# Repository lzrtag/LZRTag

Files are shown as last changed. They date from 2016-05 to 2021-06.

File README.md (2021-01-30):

# LZRTag
### ESP32-Based Lasertag

Ever wanted to set up your own system of Lasertag?
Interested in having an easily modifiable system to create your own gamemodes and styles with?
Or just looking for a cool project to try out?
Well, why not take a spin at this!

*Note:* This project is not in serious development. I (Xasin) take no responsibility for what is done with this code, and I can't guarantee it'll do exactly what I tell it to (even if I try to give it treats >:c)
However, it is a fully functional system, if you know how to use it, and it has proven itself
to be pretty reliable and useful!

## The components
In order to have a functional game, you will need at least the following:
- Two or more soldered Lasertag Sets
- A WiFi access point or a newtwork of points throughout the arena.
- A MQTT Server, preferrably in the local network, to reduce ping.
- And a system running Ruby 2.4 or better, to run the Lasertag Backend and your gamemodes

## The Electronics
*Attention:* The electronics aren't necessarily beginner-friendly. I've designed them with components no smaller than a TSOP package or a 0805 resistor, but the newer versions of the hardware do include two QFN Packages - one for a optional IMU, so it can be left out, and one for a standard I2S audio chip, for which you can use any breakout board that supports 44100Hz, 16 bit playback. If you have a hot air gun,
definitely make use of it!

The electronics are based around the ESP32, a fairly cheap, powerful, WiFi and Bluetooth capable chip. The PCB includes all necessary support structures, including a battery charge circuit and a USB to UART converter to reprogram and debug the ESP.
It comes with the following hardware:
- The ESP32 plus beefy voltage regulation, ESD protection, etc. It ain't gonna break!
- A MAX I2S decoder + amplifier, for on-board, high quality audio.
- A LSM6D IMU, to detect movement, collisions, gestures, etc.
- Peripherals to receive and send IR Signals (documented here: TODO)
- Feedback in the shape of WS2812 LEDs and a vibration motor
- Trigger, Gun Select and Reload buttons.

The vest connection is exposed with a D-SUB connector, and I2C lines are available to make
more complex add-ons easier to achieve. There's also a I2C breakout connection on the PCB itself!

The Vest itself can be as simple as a couple of Vishay 40kHz IR receivers and WS2812 LEDs, but
there is a connection for vest-specific haptic feedback, and via the I2C connection it's easy to add
more complex features.

To solder one, check out the Aisler project here: https://aisler.net/p/QLILZEMV
Or head to the "Electronics" folder and generate your own Gerber files!

## The Casing
The 3D printed casing I designed is totally optional - the electronics can be easily fitted into any other casing, provided it has space for a switch, a speaker and a couple of LEDs!
However, if you do want to print it out, there's the Fusion360 page here: https://a360.co/2Lbm2zJ

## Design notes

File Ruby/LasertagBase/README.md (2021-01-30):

# LZRTag base library gem

This is the full documentation of the LZRTag ruby gem library.
It includes examples for the different elements of this code, and even a basic
deathmatch game to show off the mechanics more interactively.

## Prerequisites
Let's first start off by installing and setting up everything that's needed
to run a LZRTag game. We'll assume you have at least one, preferrably as many as possible,
LZRTag hardware sets with the latest firmware - consult the [HackADay page](bit.ly/XASLZR) as well as the [GitHub Wiki page](https://github.com/XasWorks/LZRTag/wiki/Assembly) on soldering them up.  
We will also need a WiFi network and a MQTT Server, either local or hosted, like
Flespi.io, with the LZRTag hardware set up to connect to the server. Successful
connection is indicated by a smooth, very slow waver of the blue connection LED
on the sets. If you want to double-check connection you can subscribe to the
Lasertag/# topic on your MQTT server and check if the sets are pinging properly.

Once we are sure that the sets are connected properly run `gem install lzrtag-base`.
The latest ruby is recommended for performance reasons, however, this code should work
with anything above 2.3.

## Testing on IRB
As a first experience, I'd recommend playing with the interface class on the interactive
ruby console. It's a great way to see the immediate effects of various commands
on the set, and is kinda fun, too.

Let's first start up the console and require the library.

```IRB
irb(main):001:0> require 'lzrtag.rb'
=> true
irb(main):002:0>
```
This will load all necessary files, and will also provide a few helper functions
to access the correct classes etc.  
Next, let's establish an MQTT connection and start the handler.

```IRB
irb(main):002:0> mqtt = MQTT::SubHandler.new('localhost'); # Or your address
MQTT: localhost trying reconnect...
MQTT: localhost connected!
irb(main):003:0> handler = LZRTag.Handler.new(mqtt);
I LZR::Handler init finished
```

Awesome! The handler should now be connected to your server, and should have registered
new players. If you look at your MQTT Server, for example with MQTT-Spy, you
should see that any connected players will now have an ID.

Let's see what players the system has already registered:

```irb
irb(main):004:0> handler.each do |player| puts player; end;
#<Player:DEVICE_ID#OFFLINE, Team=0, Battery=4.19, Ping=218ms>
```

Players have a nice inspect function so they don't clutter the console too much when printed. Neat, huh?

Alright, we need to fetch one single player to play with. If you have a device ID
(their MAC, used on the MQTT network to identify them) you can use that, otherwise
use the ShotID (number, 0..255). Let's do  that now - and while we're at it,
let's identify the player:

```irb
irb(main):005:0> player = handler["BC.DD.C2.D0.63.F8"]
=> #<Player:#OFFLINE, Team=0, Battery=4.19, Heap=0, Ping=218ms>
irb(main):006:0> player.hit
```

You should have seen and heard one of the sets flashing up - that's the one we
just retrieved. We can also colour it green and make it a little brighter!

```irb
irb(main):007:0> player.team = 2
=> 2
irb(main):08:0> player.brightness = :active
=> :active
```

Alright, awesome - let's not go too deep into what you can do with the player.
That's what the Ruby documentation is for, after all.

## And now?
Well, more complex behaviours can be added with so-called hooks. These are extensions
that perform automated tasks based on different events in the game, and use the
internal "event system".  
There is a list of currently used events available, as well as documentation on
the hooks class. You can make your own, or use the standard hooks provided in this
library - it's up to you!

Since a game is way more than just behaviours though, there are also "Games".
Each game is a collection of hooks, which provide the behaviour of the game. However,
they also include a description of different phases - stuff like "initializing",
"playing", "selecting teams", etc.  
The application can seamlessly switch between phases of a game, with each phase
defining which hooks to enable or disable and what to do every game tick.

It's best to look right into the documentation on those classes, since demonstrating
them bit by bit isn't really possible.

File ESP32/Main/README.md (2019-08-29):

# The Lasertag ESP32 Core code

This code is what drives the newest version of the Lasertag.
Written in C++, this code here handles graphics, shot sounds, as well as communication with the Ruby-Side server code, via a MQTT Channel.

All hardware-related systems can be found under main/core/setup.cpp
Graphics are executed in main/fx/animatorThread.cpp, while gun profiles are found under main/weapons/

If you want to add your own weapon, animation feature, communication code or similar, it's best to open an issue and contact the team.
Documenting this work is a bit tough, but explaining specifics should be easy!

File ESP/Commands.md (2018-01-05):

### Immediate commands
Number | Short Desc. | Data
:--- | --- | ---
A000 | Shot cfg | 0 = Normal shot
E000 | Trigger status changed
E001 | Shot detected | Player, ShotID
A010 | Vibrate 	| Time (in MS, up to 2^16 ms)
A011 | Buzzer 	| Time (in ms), Start, End (in Hz)
A012 | Vest Blink Override | Level + time in segments

### Config commands
Number | Short Desc.
:--- | ---
A100 | Set Player ID
A101 | Set Player Team (0-7)
A110 | Set vibration pattern
A200 | Set vest visibility level

###### A200
Visibilitiy levels:
- 0 = Absolutely no lights whatsoever, dimmed nozzle flash.
- 1 = Occasional dimmed blink, dimmed nozzle flash.
- 2 = Occasional bright blink, full nozzle flash.
- 3 = Dimmed with occasional blink, full nozzle flash.
- 4 = Full light, full nozzle flash.
- 5 = Special Mode - Full with white flashes, full nozzle flash with dim background.
- 6 = Wave-Mode (in low brightness)
- 7 = Wave-Mode (in full brightness)

- 10 = Full brightness, constant white flashing. Used for hit and death animation

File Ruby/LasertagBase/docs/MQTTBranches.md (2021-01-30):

# MQTT Branch setup description

## Game Branches

- Lasertag/Game/Events/Hits
- Lasertag/Game/Controls/+
	- SetPhase
	- SetGame
- Lasertag/Game/Phase/Valid
- Lasertag/Game/ParticipatingPlayers
- Lasertag/Game/KnownGames
- Lasertag/Game/CurrentGame
- Lasertag/Game/Phase/Current

## Weapon Branches
The weapons are the main unit of the Lasertag system. As such, they use a specific
branch setup to minimize traffic to them, while making code maintaining easier.

The basic branch setup is:
> Lasertag/Players/**ID**/**Keys...**

- **ID** is the MAC of the Player, allowing unique identification of
	each set out of the box.
- **Key** is a one- or two-layer key of the attribute to change.
	Attributes are grouped, making it easier to subscribe to one group of attributes
	without having to worry about the others.

In the following, the different groups of keys will be outlined, followed by
a description of each attribute per group.

### Non-Grouped attributes

|Keys|Data|Descrition|Retained|
|--|--|--|--|
|Connection|String|LWT Topic of the sets. "OK" if connected.|Yes|

### Config attributes

Any attributes under this category can be found under "/CFG/**KEY**".
They are slow-changing configuration parameters for the weapons.

|Key|Data|Descrition|Retained|
|--|--|--|--|
|Team|STR Number|Team number, 0 to 7|Yes|
|Brightness|STR Number|Brightness preset number. In Ruby, handled by symbols|Yes|
|Name|String|User-set name of the weapon|Yes|
|Dead|"1" or "0"|Sets the alive-ness of the gun.|Yes|
|Dead/Timed|STR Number|Number, in seconds, to kill the weapon for. Auto-revives|No|
|GunNo|STR Number|Gun preset number. 0 or "" disable shooting|Yes|
|Marked|STR Number|Color to mark the set with. 1-7 use team colors, custom colors can be used|Yes|
|Heartbeat|"1" or "0"|Enables/Disables heartbeat of the weapon|Yes|
|Hit|STR Number|Number, in seconds, to make the gun show that it's hit|No|
|Vibrate|STR Number|Number, in seconds, for which to make the gun vibrate|No|
|Reload|"1"|Trigger a gun-side reloading|No|

### Sound attributes

Any attributes under this category are found under "/Sound/**KEY**"
They all relate to noises the gun can make.

|Key|Data|Descrition|Retained|
|--|--|--|--|
|Note|uint32_t[3]|Raw note play data. Frequency(Hz), Volume (0..2^16), Duration(ms)|No|
|File|String|Name of a raw audio file to play.|No|

### Hardware attributes

Any attributes under this category are found under "/HW/**KEY**"
They all relate to the hardware of the system, such as battery etc.

|Key|Data|Descrition|Retained|
|--|--|--|--|
|Ping|uint32_t[3]|Battery, free-heap and ping data|No|
|NSwitch|STR Number|Navigation switch press info (0-3)|No|
|Gyro|String|Clear string of the pose the gyroscope is reporting|Yes|
|BeaconDetect|STR Number|Number of the beacon signal that was detected (0-255)|No|

### Statistics Attributes

Any attributes under this category are found under "/Stats/**KEY**"
They all relate to various game statistics that do not directly influence the hardware, but are still relevant to the game and how it plays out.

|Key|Data|Descrition|Retained|
|--|--|--|--|
|HP|STR Number|Float number, 0  to 100 (or more with shields)|Yes|
|Ammo|uint32_t[3]|Current Clip ammo, max clip size and reserve ammo|No|
|Ammo/SetClip|STR Number|Set the amount of ammo in the player's clip|No|
|Ammo/SetReserve|STR Number| Set the amount of ammo in the player's reserve|No|

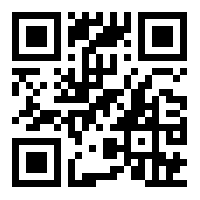
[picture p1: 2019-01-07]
HackadayLink.png

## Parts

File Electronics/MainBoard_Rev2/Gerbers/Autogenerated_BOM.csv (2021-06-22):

Id | Designator | Package | Quantity | Designation | Supplier and ref
1 | BT1 | PinHeader_1x02_P2.54mm_Horizontal | 1 | Battery_Cell
2 | D402,D401 | IN-PI42TAS | 2 | IN-PI42TAS
3 | J101 | RJ45_Amphenol_54602-x08_Horizontal | 1 | 54602-908LF
4 | D30 | PinHeader_1x02_P2.00mm_Vertical | 1 | SFH4545
5 | D1 | PinHeader_1x04_P2.00mm_Vertical | 1 | COM-12999
6 | C401,C50,C54 | C_0805_2012Metric | 3 | 1uF
7 | C201 | C_0805_2012Metric | 1 | 0.1uF
8 | U401 | VSSOP-10_3x3mm_P0.5mm | 1 | DRV2605
9 | R8,R9,R1,R7,R30 | R_0805_2012Metric | 5 | 220R
10 | J5 | PinHeader_1x02_P2.00mm_Vertical | 1 | Conn_01x02_Male
11 | TP1,TP2,TP3 | TestPoint_Pad_2.0x2.0mm | 3 | TestPoint
12 | C5 | C_1206_3216Metric | 1 | 47uF
13 | D8 | D_SOD-123F | 1 | D_Zener_ALT
14 | J4 | nav_switch_COM_08184 | 1 | Conn_01x04_Male
15 | C4,C52,C9,C53 | C_0805_2012Metric | 4 | 10uF
16 | AMP1 | QFN-16-1EP_3x3mm_P0.5mm_EP2.7x2.7mm_ThermalVias | 1 | MAX98357A
17 | C2,C31,C8,C19,C3 | C_0805_2012Metric | 5 | 100nF
18 | R6,R5 | R_0805_2012Metric | 2 | 2.2k
19 | R52,R13,R14 | R_0805_2012Metric | 3 | 10k
20 | R55,R56 | R_0805_2012Metric | 2 | 50k
21 | U4 | SOT-753 | 1 | MAX1555EZK_T
22 | J3 | USB_Micro-B_Wuerth_629105150521 | 1 | USB_B_Micro
23 | DUSB1 | LED_0805_2012Metric | 1 | LED
24 | U13 | SSOP-20_3.9x8.7mm_P0.635mm | 1 | FT231XS
25 | Q5,Q6 | SOT-23 | 2 | Q_NPN_BEC
26 | R12 | R_0805_2012Metric | 1 | 220
27 | R15 | R_0805_2012Metric | 1 | R_Small
28 | U50 | SOT-223 | 1 | AP2114H-3_3TRG1
29 | U3 | LGA-14_3x2.5mm_P0.5mm_LayoutBorder3x4y | 1 | LSM6DSMTR
30 | H6 | DragonIcon | 1 | MountingHole
31 | H3 | KiCad-Logo_5mm_SolderMask | 1 | MountingHole
32 | H4 | OSHW-Logo_5.7x6mm_SilkScreen | 1 | MountingHole
33 | J1 | PinSocket_1x04_P2.54mm_Vertical | 1 | Conn_01x04_Female
34 | H2,H1 | MountingHole_3.2mm_M3_DIN965 | 2 | MountingHole
35 | SWPWR1 | PinHeader_1x02_P2.54mm_Vertical | 1 | SW_SPST
36 | DPWR1 | D_0603_1608Metric | 1 | D_Schottky
37 | TRGR1 | PinHeader_1x02_P2.54mm_Vertical | 1 | SW_Push
38 | VBR1 | PinHeader_1x02_P2.54mm_Vertical | 1 | Motor_DC_ALT
39 | D4,D5,D3,D2 | LED_WS2812B_PLCC4_5.0x5.0mm_P3.2mm | 4 | WS2812B
40 | Q30 | SOT-23 | 1 | PMBT2222A
41 | QPWR1 | SOT-23 | 1 | IRLML6402
42 | U1 | ESP32-WROOM-32 | 1 | ESP32-WROOM-32

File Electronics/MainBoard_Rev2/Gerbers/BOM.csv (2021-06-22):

Quantity | Digi-Key_PN
1 | ESP32-WROOM-32D (16MB)
1 | 54602-908LF
1 | A3882R-05C-ND
2 | IN-PI42TASPRPGPB
1 | MAX98357AETE+TCT-ND
1 | AS04008CO-R
1 | 455-1749-1-ND
1 | AO3419
2 | CD0603-B0340RCT-ND
1 | CKN9565-ND
1 | AP2111H-3.3TRG1
1 | MAX1555EZK+TCT-ND
1 | PTVS3V3S1UTR
1 | 732-5960-1-ND
1 | 768-1129-1-ND
4 | 1727-2956-1-ND
1 | 1528-1104-ND
1 | EG1701-ND
1 | LV101040A
1 | SFH4545
1 | LSM6DSMTR
1 | 1568-1214-ND
1 | 1568-1827-ND
1 | DRV2605LDGSR

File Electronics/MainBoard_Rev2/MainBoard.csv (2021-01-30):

Quantity | Digi-Key_PN
1 | 1904-1025-1-ND
1 | AE10921-ND
1 | 1830-1068-1-ND
1 | 160-1172-1-ND
1 | MAX98357AETE+TCT-ND
1 | 668-1517-ND
1 | 455-1749-1-ND
1 | IRLML6402PBFCT-ND
2 | CD0603-B0340RCT-ND
1 | CKN9565-ND
1 | AP2114H-3.3TRG1DICT-ND
1 | MAX1555EZK+TCT-ND
1 | F7701CT-ND
1 | 732-5960-1-ND
1 | 768-1129-1-ND
4 | 1727-2956-1-ND
1 | 1528-1104-ND
1 | EG1701-ND
1 | 1597-1244-ND
1 | 475-3581-ND
1 | 497-15383-1-ND
1 | 1568-1214-ND
1 | 1568-1827-ND

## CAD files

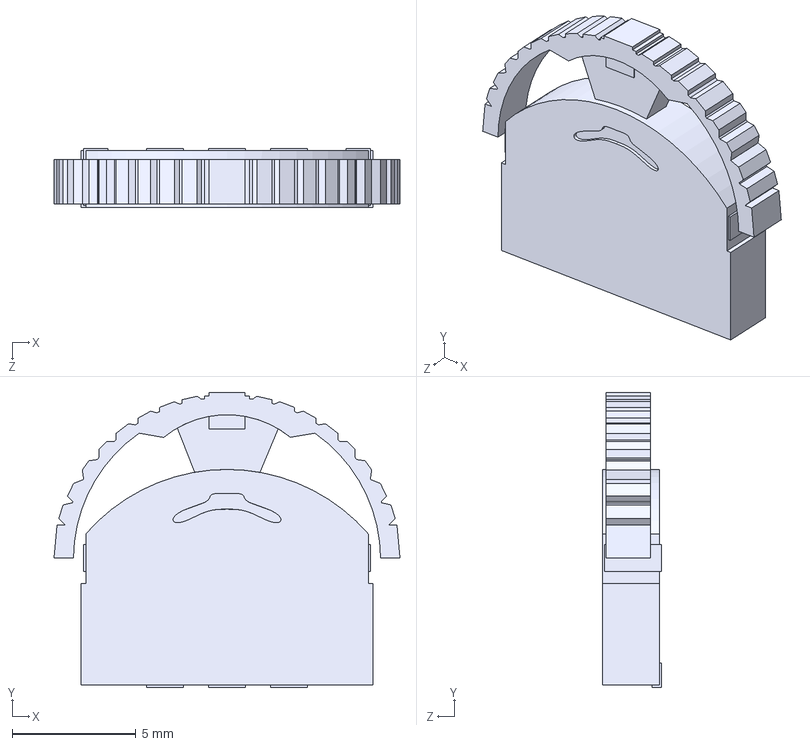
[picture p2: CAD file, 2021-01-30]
Electronics/MainBoard_Rev2/nav_switch_COM/NAV_SWITCH.STEP
14.0 x 11.9 x 2.40 mm

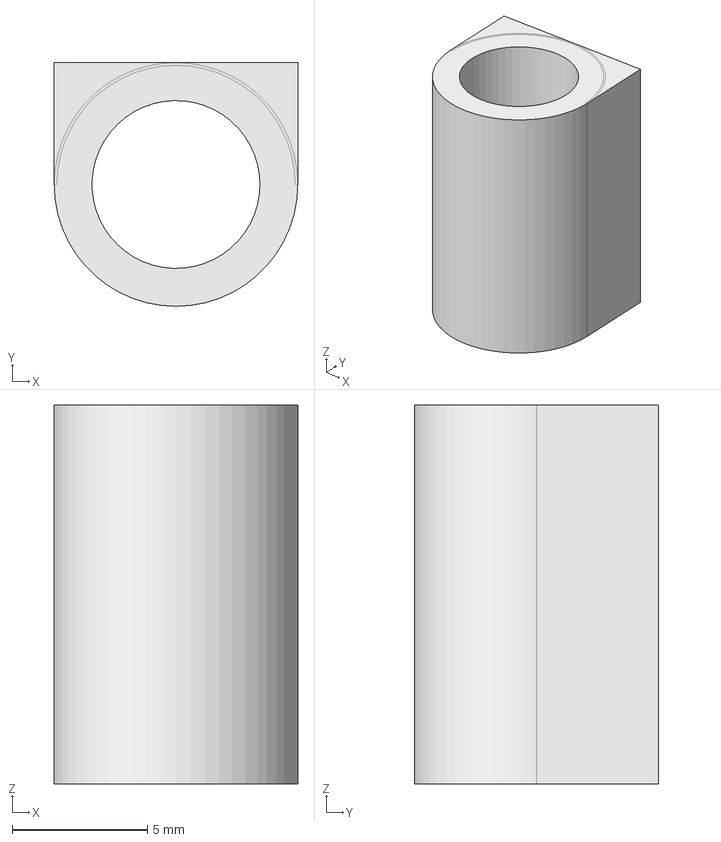
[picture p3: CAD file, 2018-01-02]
Models/Gun/VibratorCover.fcstd
9.00 x 9.00 x 14.0 mm

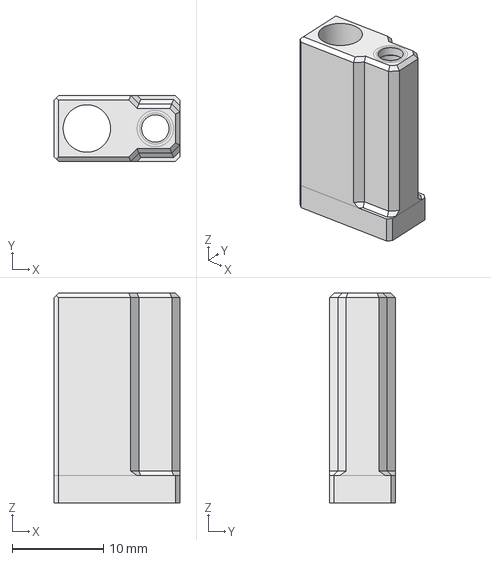
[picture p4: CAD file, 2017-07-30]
Models/Prototypes/EDGE_IRFocus.fcstd
13.8 x 7.20 x 23.0 mm

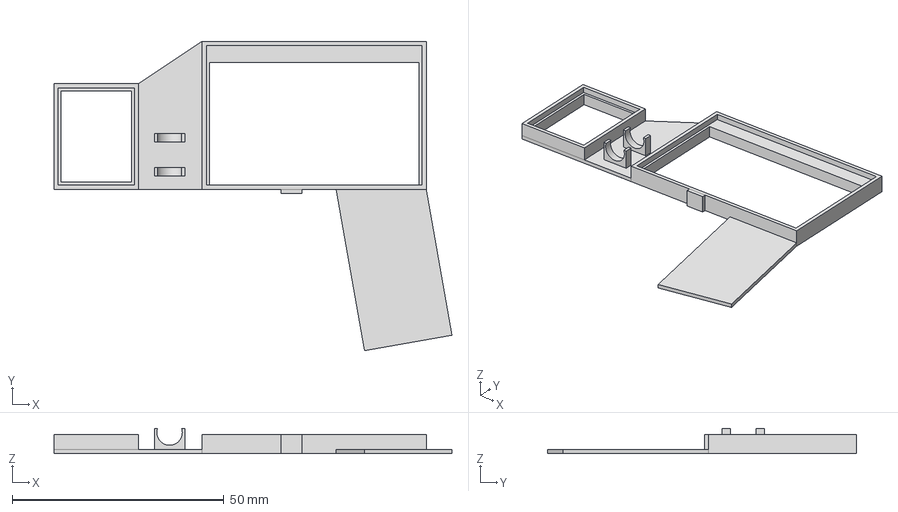
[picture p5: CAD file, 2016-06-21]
Models/Prototypes/Prototype_Holder/M_Gun_Holder.fcstd
94.1 x 73.1 x 6.00 mm

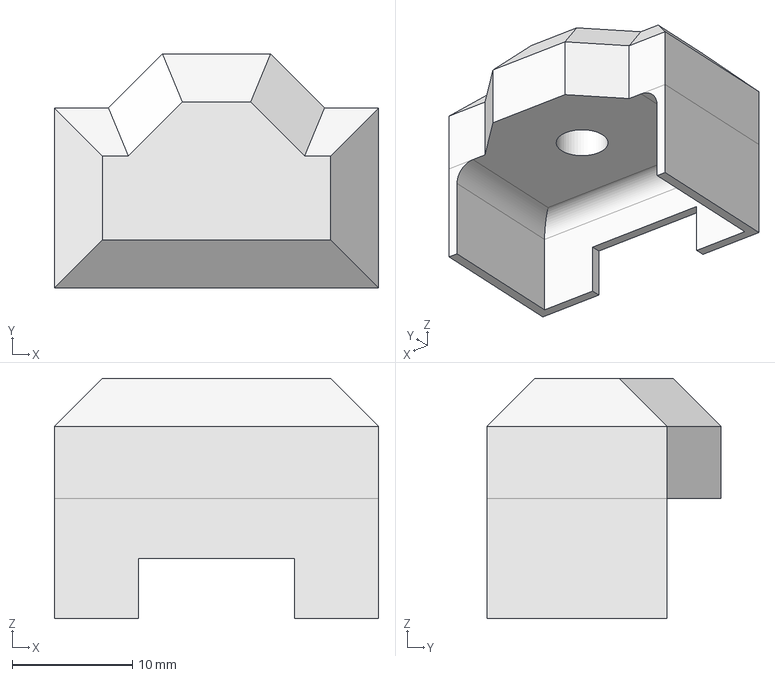
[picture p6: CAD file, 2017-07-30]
Models/ShoulderPads/RGBCovering.fcstd
27.0 x 19.5 x 20.0 mm

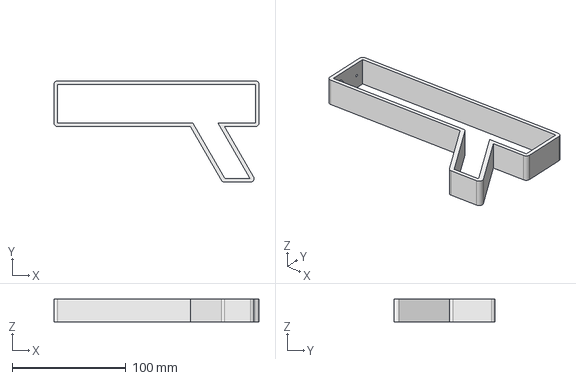
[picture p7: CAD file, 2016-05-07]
Models/Gun/Gun.FCStd
180.0 x 88.9 x 20.0 mm

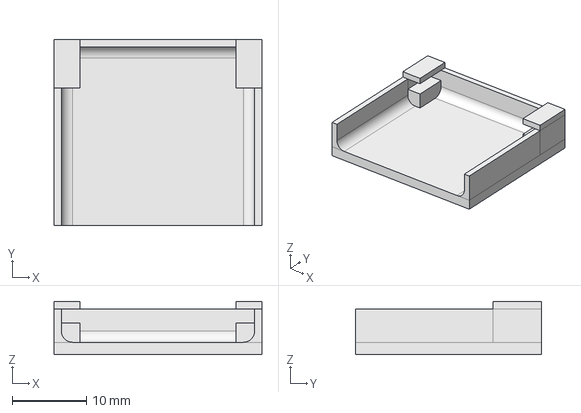
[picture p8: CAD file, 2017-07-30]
Models/ShoulderPads/BottomCovering.fcstd
28.0 x 25.0 x 7.16 mm

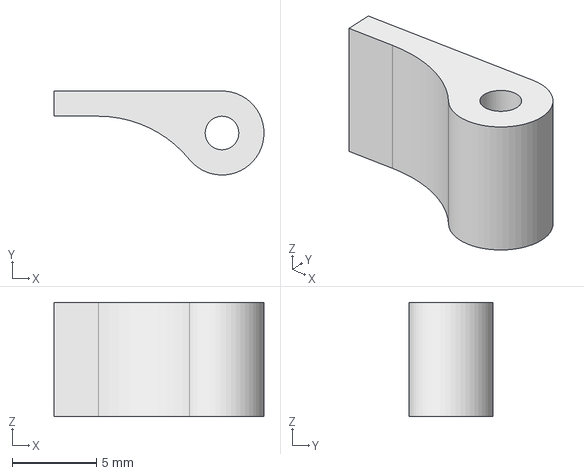
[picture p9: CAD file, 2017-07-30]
Models/ShoulderPads/SecurityPinClip.fcstd
12.5 x 5.00 x 6.80 mm

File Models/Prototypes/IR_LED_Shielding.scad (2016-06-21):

$fs = 0.8;

module RGB_Led() {
	
	sHeight = 15;
	difference() {
		union() {
			children();
			
			cylinder(d = 6, h = sHeight);
		}
		
		translate([0, 0, -0.1]) cylinder(d = 5, h = sHeight + 1);
	}
}

module IR_Shield() {
	
	sHeight = 10;
	fDiam = 2;
	
	$fs = 0.1;
	
	difference() {
		hull() {
			cylinder(d = 4, h = 0.1);
			translate([0, 0, sHeight]) cylinder(d = fDiam + 1, h = 0.1);
		}
		hull() {
			translate([0, 0, -0.1]) cylinder(d = 3, h = 0.1);
			translate([0, 0, sHeight + 0.001]) cylinder(d = fDiam, h = 0.1);
		}
	}
}

module IR_Led() {
	difference() {
		union() {
			children();
			
			cylinder(d = 4, h = 5);
			
			translate([0, 0, 4.9]) IR_Shield();
		}
	translate([0, 0, -0.1]) cylinder(d = 3.2, h = 5.1001);
	}
}

module IR_Set() {
	RGB_Led()
	translate([8, 0, 0]) IR_Led() translate([-8, 0, 0]) 
	
	hull() {
		cylinder(d = 6, h = 1);
		translate([8, 0, 0]) cylinder(d = 4, h = 1);
	}
}

IR_Set();

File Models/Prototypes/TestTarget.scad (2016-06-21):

$fs = 0.8;

$wallThickness = 0.6;

casingBottomRadius 	= 26;
casingTopRadius 		= 15;
casingHeight 			= 22 - 7;
	

screwHead = 6;
screwRadius = casingBottomRadius - 5;

module casing_shell_inner() {
	$fn = 6;
	cylinder(r1 = casingBottomRadius - $wallThickness,
					r2 = casingTopRadius - $wallThickness,
					h  = casingHeight - $wallThickness);
}

module casing_shell() {
	difference() {
		$fn = 6;
		cylinder(r1 = casingBottomRadius, r2 = casingTopRadius, h = casingHeight);
		casing_shell_inner();
	}
}
		

module casing_screw_negative(position) {
	translate(position + [0, 0, 3]) cylinder(d = screwHead, h = $wallThickness + 10.001);
	translate(position - [0, 0, 10]) cylinder(d = 3.1, h = 100);
}

module casing_screw_positive(position) {
	intersection() {
		translate(position) cylinder(d = screwHead + $wallThickness*2, h = 100);
		casing_shell_inner();
	}
}

module casing_with_screws() {
	difference() {
		union() {
			casing_shell();
			for(i=[0:120:360]) rotate([0, 0, i]) casing_screw_positive([0, -1.5 - $wallThickness + screwRadius, 0]);
		}
		for(i=[0:120:360]) rotate([0, 0, i])
		casing_screw_negative([0, -1.5 - $wallThickness + screwRadius, 0]);
	}
}

module electronics_holder() {
	elX = 24.36; 
	elY = 19;

	zUp = 2 + $wallThickness;
	
	$wallThickness = 0.6;
	
	translate([elX + $wallThickness *2, elY + $wallThickness *2, 0] /-2)
	difference() {
		cube([elX + $wallThickness *2, elY + $wallThickness *2, zUp + $wallThickness]);
		translate([$wallThickness*2, $wallThickness*2, 0]) cube([elX - $wallThickness*2, elY - $wallThickness*2, zUp + $wallThickness]);
		translate([$wallThickness, $wallThickness, zUp]) cube([elX, elY, 100]);
	}
}

module casing_bottom() {
	difference() {
		union() {
			$fn = 6;
			cylinder(r = casingBottomRadius, h = $wallThickness);
			
			difference() {
				cylinder(r = casingBottomRadius, h = 7);
				cylinder(r = casingBottomRadius - $wallThickness, h = 8);
			}
			
			for(i=[0:120:360]) rotate([0, 0, i]) translate([0, -1.5 - $wallThickness + screwRadius]) 			cylinder(d = screwHead, h = 7, $fn = 13);
		}
		for(i=[0:120:360]) rotate([0, 0, i]) translate([0, -1.5 - $wallThickness + screwRadius])
			cylinder(d = 3.1, h = 7);
	}
}


translate([0, 0, 7]) casing_with_screws();
%rotate([0, 0, 30]) electronics_holder();
%casing_bottom();

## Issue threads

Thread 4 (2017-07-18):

Modify schematics/Prototypes for ESP UART

Xasin, 2017-07-18:
Basically, the KiCAD schematics will have to be updated (which should have been done anyways :S), and both will have to be re-soldered in order to allow for usage of the chip's UART coms.
TWI would have been nice, sure, but since the ESP-01 has a fitting hardware implementation that supports receiving and sending ... This works better.

Xasin, 2017-07-25:
Alright!
The UARTs are fully functional, including proper receive and transmit code for both ESP and AVR.

See branch ESP_Implementation for more details.

Closed 2017-07-25.

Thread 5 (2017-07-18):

Conceptualize MQTT<->ESP<->AVR Communication

Xasin, 2017-07-18:
Since the ESP will be acting as a bridge between these different software levels, it is now important to come up with a fitting and "smooth" concept to handle data.

We could either:
- Be very server-heavy, and have ESP and AVR just be "slaves" to this setup, acting out on that received data.
- Be AVR-Heavy, letting that chip handle variable processing, and leaving the ESP as a simple translator between MQTT and the hardware-level side.
- Or be ESP-Heavy, with the ESP-Chip computing most of the data, sending important bits to MQTT and telling the AVR what to do.

Personally, I would go for the last option.
It would give us the most processing power for that stuff (with floats, 32-bit processing power and more RAM), and since the communication between AVR and ESP will be so close and error-free, it would be easy to have the ESP "master" the AVR.

We also have to think about how to implement things like special effects, how damage is received, and especially: *Shot Arbitration*

I know it's a lot, but it would be nice to come up with a **simple** and hackable system that allows for easy expansion of everything :3

Xasin, 2017-07-19:
After performing a short test on different pings, I've got pretty promising results!

Here's a graph depicting the Round-Trip ping time, measured by sending a Timestamp to the MQTT Network and recording its arrival time.
The ESP was connected over my mobile-phone ((which had its mobile hotspot open), which connected via the internet to my local MQTT server.

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

As you can see, most pings are in the 250ms region, with only a few of them exceeding a second.
This isn't perfect, but sufficient for most cases, as the lasertag-weapons will be capable of running fairly stand-alone.

A direct WiFi connect was, understandably, hard to beat.
I got a constant ~20ms Round-Trip time for the ping.
*HOWEVER*, at the same time the signal reach is very limited and would require us to set up a fairly large outdoor WiFi net to achieve similar coverage.

My vote is to use our phone's mobile hotspots. It's a bit slower but covers any area with normal broadband internet access.

:satellite: for using our phones,
:signal_strength: for WiFi.

Closed 2017-08-11.

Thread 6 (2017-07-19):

Design, then solder the Receivers!

Xasin, 2017-07-19:
Not really that hard ...
I just need to design up the schematics for the receivers (with MOSFETs to get the RGBs working, and a properly coupled data line ^^)

Soldering should be quick to do, too.

Closed 2017-07-30.

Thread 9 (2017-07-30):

Phase out AVR-Side game handling.

Xasin, 2017-07-30:
There's lotsa code in there that we don't need any more, since the actual handling of game variables will be done inside the ESP, or via the MQTT network (for the "weirder varieties)

To properly phase out the AVR-Side handling we also need a good Lasertag-API, as well as a few more sophisticated backbones for effects etc.
That way, the ESP can focus on immediate actions, while the AVR can receive and send signals, play noises, vibrate, etc.

Xasin, 2018-09-07:
Pretty sure that in the current state, not much, if any, game handling is done on the AVR side.
In any case, there won't be any need for this when the entire system is moved to the ESP32, so this issue can be safely closed.

Closed 2018-09-07.

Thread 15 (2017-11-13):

Improve wireless data transfer by using wait_for of the Ruby Library

Xasin, 2017-11-13:
Self explanatory - by using `wait_for`, a data block can be sent to the ESP.
It can then write it and issue an "OK" back to the sending script, or a "FAIL" otherwise. This way, data transfer can happen much faster in direct networks, and improves reliability in slower networks.

Xasin, 2017-11-22:
Just created a new branch for that, `Better_Data_Transfer`

Xasin, 2017-11-22:
The goals have changed to an easier to use and stable "on the fly" data transfer system, which will be integrated directly into the Lasertag game code.

Xasin, 2017-11-28:
Nooope, one last thing needs to be done:
Put the data-transfer related code into a module. Please.

Closed 2017-11-29.

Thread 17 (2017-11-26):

Add heartbeat-style vibration

Xasin, 2017-11-26:
In order to signal the player some Form of immediate danger, like being low on health, a heartbeat vibration should be added ESP-Side that gives the player a sense of tension, without making him more or less visible.

Xasin, 2018-01-05:
Closed by #34 <3

Closed 2018-01-05.

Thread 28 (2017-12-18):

Add simple JSON-Output of connected players and game stats

Xasin, 2017-12-18:
First things first for the Web-Server: A simple JSON output of the status of currently connected players etc.

This relies on #25, so that needs to be done beforehand.
Once it's completed we should:
- [ ] Set up a Sinatra folder structure
- [ ] Add a first base-class that can be hooked up to the Lasertag, and outputs raw JSON on appropriate URIs
- [ ] *Maybe* add a first basic, somewhat fancy view of a table of connected players and their different informations, like battery, team, dead/not, etc.

Xasin, 2018-01-06:
Closed by 93d21f6361dd741479d57cfe1cec1f58d74e8340

Closed 2018-01-06.

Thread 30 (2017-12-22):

Add proper, centralized "slow-pub" system

Xasin, 2017-12-22:
Since apparently, the ESP chips dislike quick successive MQTT messages, a new system must be made to properly send them out.

I would say that a central thread for all players, running every 200ms and sending out messages, should be fine.
A per-player system is fine too but does not scale very well.

Xasin, 2018-01-02:
This is no longer necessary, as the code seems to run fine with the new, better timed `OK` of the ESP chips.

Closed 2018-01-02.

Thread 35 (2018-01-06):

Add in "last modified" timing

Xasin, 2018-01-06:
In order to allow for JSON/AJAX streaming events (i.e. long polling for live updating), each Lasertag player should keep track of when it was last modified.
Each important event (like death, team change, battery change etc.) would update this timestamp and trigger an "updated" event in the main lasertag code.

For updating events, such as the live-updated web-interface, this "last updated" UNIX timestamp could be used to then select out the information that needs to be streamed to the server.

Closed 2018-09-07.

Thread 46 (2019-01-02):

Redesign the circuit to ESP32-Only

Xasin, 2019-01-02:
Whheee, finally got some time to work on this!

Let's see what still needs to be done...
- [x] Muzzle WS2812
- [x] Four body WS2812
- [x] Lay out important PCB elements
- [x] Route I/O accordingly

Xasin, 2019-09-05:
Definitely closed as of Revision 3.2

Closed 2019-09-05.

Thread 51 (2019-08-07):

Rework the reloading system

Xasin, 2019-08-07:
*Detail later!*

Rework ammo to have clips, different reload times, max ammo to run out of, ammo regeneration as well as "Reload by holding up" with the new IMU.

Xasin, 2019-10-29:
Alright, let's define more clearly what we want to do here:

- [ ] Two more weapon states, those being "Reloading" and "Post-Switch delay"
- [ ] A per-weapon clip and total ammo, as well as clip size parameter
- [ ] A better reload behavior with forced reload on empty clip, reload phase delay, per-reload-phase ammo recovery, and reload from MQTT option
- [ ] Better ammo data pushing to MQTT including setting total ammo and clip ammo, also encompassing "-1" ammo amount to enable infinite shots.
- [ ] Possible overrides for shot and reload speeds, as a sort of "power-up", though this isn't really necessary.

Xasin, 2019-11-04:
Closed by PR #76!

Closed 2019-11-04.

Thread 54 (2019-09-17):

Add LSM6D3 gyro support

Xasin, 2019-09-17:
Issue to focus on the integration of the new 6-DOF IMU that the Lasertag now possesses.
Integration shouldn't do too much fancy stuff, apart from maybe an MQTT exposure of a few interesting parameters like `has moved`, `speed`, etc.

Closed 2019-09-25.

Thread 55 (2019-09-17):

Add MQTT Button output

Xasin, 2019-09-17:
New feature of the hardware, and it's a sexy one, is the three-way navigation switch!
In order to use it, we just need to
- [] output the different selection events via MQTT,
- [] provide a ruby backend event to do things with :>

Xasin, 2019-09-20:
Closed as #60 has been merged in and seems functional!

Closed 2019-09-20.

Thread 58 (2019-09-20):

Rework the Ruby game system

Xasin, 2019-09-20:
Mainly:

Implement states, and use these states in order to switch certain hooks on/off
A normalized set of states should do. In the same vein, a game timer and progress tracking would also be useful!

Xasin, 2019-10-16:
Hell yeh, closed in #68!
And what a beauty that is :>

Closed 2019-10-16.

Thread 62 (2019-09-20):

Switch to XIRR implementation

Xasin, 2019-09-20:
Using XIRR would allow the Lasertag to interact with other IR devices like the IR beacons, instead of having to wedge in code to read them in the current implementation.

It would also make maintaining this a bit easier!

Xasin, 2019-10-23:
Closed as of PR #74

Closed 2019-10-23.

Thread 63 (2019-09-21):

Switch over to a DIY communcation

Xasin, 2019-09-21:
The ESP MQTT implementation seems to be crashing regularly. The reconnect is fast, of course, but it's still an annoying temporary loss of connection, which could cause problems.

I'd first try updating the XaQTT wrapper to add better thread safety, but if that fails, a custom UDP connection might provide better stability and speed!

Xasin, 2019-10-22:
Closed as the issue was a faulty WiFi connection
Setting up a stronger access point yields very smooth behaviour ^^

Closed 2019-10-22.

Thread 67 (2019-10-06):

Document Ruby more!

Xasin, 2019-10-06:
The current documentation is sparse, up to non-existent
This is a bit of a problem as it will make it hard for other people to properly write their own games.
Further yet, our own work with the system is being halted due to needing to look up event names and such.

A good documentation of the Ruby API, events and MQTT Topics, as well as a proper Bundler list of required gems to run the system would be appropriate.

travisghansen, 2019-10-18:
Just looking into this project with a few others for fun...any interest in creating a docker image? I've not got much experience with ruby but I'll see what I can do if you're interested.

Xasin, 2019-10-18:
@travisghansen Thanks for your interest!
A docker image as quickstart could be quite interesting, actually, since this project is growing in a bit of complexity ^^'

However, if you only want to test out the Ruby backend, I will soon publish a first version of the software as a rubygem, which makes installation as easy as `gem install lzrtag-backend`

If you're patient, I'll be writing a guide on setting up the infrastructure soon :)
Otherwise, you can poke me via [Telegram](t.me/Xasin) or [HackADay](bit.ly/XASLZR) and I could help you set up your system now ^^

travisghansen, 2019-10-18:
We'll be working on it over the course of several months so no rush. I did manage to get gems installed but it was failing to launch (not sure if I was even launching it correctly). I noticed the mqtt server was hard-coded as well so I hacked that and eventually got it to connect but still was getting some failure that appeared to be bad syntax.

Also we started looking into printing the guns. Do you have any stl files that are just the parts needed for printing? We're not 3d modeling folks but the fusion 360 stuff looked to include way more that what should be printed.

Thanks!

Xasin, 2019-10-18:
@travisghansen There is definitely a bit too much Ruby code floating around right now that doesn't really do much. I'll move those into a "deprecated" folder.

Also, the current system isn't meant to just be a deployable server and more of a base code for other people to code their own games on. As such, you're supposed to write your own Ruby script that at the very least instantiates the MQTT server connection and a few games.

You can see a more functional test script under Ruby/LasertagBase/lib/lzrtag/test.rb, and as said, I am working on much better documentation right now :>

And I could definitely upload a few 3D model files.
Those would be put onto HackADay, and might require a bit of tweaking to get working - the current system is designed to be printed with a multi-material printer, but I do it by manually swapping filaments mid-print with a small helper script and Prusa Slic3r's SEMM function.

travisghansen, 2019-10-18:
Oh wow. That might be a bit advanced printing for us :) we'll see. I'll just wait on the Ruby front then.

Thanks!

Xasin, 2019-10-18:
@travisghansen
The multi-material nature of the print is optional. Technically, the whole thing can be done with a single material too - the only downside would be that you'd lack the light diffusion on the side plates of the weapon, but you could just stick a piece of paper over that instead, or hot glue it :)

I don't have access to the computer with the model on it until Monday, but I'll send over the files then.

travisghansen, 2019-10-18:
Sounds great, no rush at all from our side.

Xasin, 2019-10-20:
Alright, closed by the latest PR #71
There are a few examples and a better README on the library code now :>

Closed 2019-10-20.

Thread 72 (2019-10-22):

Improve player MQTT topic init and deinit

Xasin, 2019-10-22:
The current system only handles closing a Player's MQTT topics, which potentially leaves them in an undefined state.
As such, we should consider improving how MQTT topics are cleared, and also add a good way to prep and clean topics when a player connects!

There should also be a method to reset players at the end of a game, to ensure a clean slate when starting a new one.

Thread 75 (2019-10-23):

Replace puts with proper Logger useage

Xasin, 2019-10-23:
The current Ruby code is a bit messy - it would be great to use a proper Logger system to improve longer-term debugging (by pushing logs into a file), and make things look a LOT more professional.

We do not need that much extra logging, but it would still be nice to push important things (phase switching, game states, etc. etc) to the logs.

Xasin, 2019-10-29:
Alright - with the new mini-gem "XasLogger" and it's mix-in, a really lovely and smooth way of logging Lasertag code now exists, and has been slapped into the library where needed.
We'll polish as we go, but everything important has been replaced.

Closed 2019-10-29.

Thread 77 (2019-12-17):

No BOM - List in documentation.

FreakyFerrox, 2019-12-17:
Would you be so kind to add a Built of Material List.
From the KiCad file I am not able to extract a usable Part/Component-List.

thx

Xasin, 2019-12-18:
Hi @FreakyFerrox!

Thanks for the reminder. I was going to get back to the Lasertag this Christmas holiday and I will then make a proper BOM, probably with MPN or DigiKey part numbers.
Some of the modules aren't on LCSC sadly, but I can check.

For now, I have a pretty much complete BOM on the Aisler project, but since that can't be exported (I think) I can see where you're coming from.

Xasin, 2020-01-01:
@FreakyFerrox is the BOM still needed or were you able to figure something out?
Now that all the Christmas and new year stuff is over I'd have a bit of time to sort a list out. I will have to change a part though since the IR LED I was using is no longer available!

FreakyFerrox, 2020-01-09:
Hi Xasin!

Sorry for the delay, somehow I skippt the notification mail...

The BOM List is still needed. One of my friends tried to get a Part/Component List of out of the shematic with kiCAD but that didn't work well.

And we don't want to use Aisler, it's a little expensive... ^^

Xasin, 2020-01-11:
@FreakyFerrox I'll get to that this weekend, I hope.
My Laptop broke down so first that'll be fixed <.<

Where will you be getting your components from! Everything I chose can be bought off of DigiKey, while LCSC does not necessarily have some parts (I checked, would've bought from there <.<)

Just as a word of warning ^^'

Xasin, 2020-01-12:
@FreakyFerrox I have a DigiKey parts list here.
I think I can make a Manufacturer Part Number as well, which might be better in the long run...

https://hackaday.io/project/160804-lzrtag-flexible-diy-lasertag/files

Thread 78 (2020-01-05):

Unable to build ESP code

spectre3ooo, 2020-01-05:
I haven't been able to build the code for the ESP32.  I'm getting this error:
`In file included from ../main/main.cpp:22:0:`
`../main/core/setup.h:11:34: fatal error: xasin/BatteryManager.h: No such file or directory`

I am building on Windows, and I've also cloned the XasCode repo to
`C:\Development\XasWorks\XasCode\`.  I set the `XASCODE_PATH` environment variable to this path.  I'm running `idf.py build` from within `ESP32/Main` when it returns that error.

I pasted the full console output of the build here: https://gist.github.com/spectre3ooo/de4ae4e4b37ab2f1d9d206532187189c

Any ideas?

Xasin, 2020-01-05:
I have a good idea - you are using the latest version of the ESP IDF, right?
I haven't been able to make my own libraries compile under the new compiler system, the last time I tried to get it to work it didn't recognize my files.
Use the ESP IDF v3.3 and try again

I'll be porting my libraries soon though, now that the v4 IDF has been out for a while and *should* work.

spectre3ooo, 2020-01-05:
I'm using v3.3.1.  Should that work, or should I install v3.3?

Xasin, 2020-01-05:
@spectre3ooo v3.3.1 is also fine.
However, keep in mind that the build system changed - you now need to call "make" and "make flash" or "make monitor" to start the build process.

Also, try checking out to "dev_3.2" or "dev_3.2_stats"
I left the whole thing in a yet unmerged state since I got slightly overwhelmed by my University exams... Proooobably not the best idea.

spectre3ooo, 2020-01-06:
Good to know.  I've been trying to run `idf.py build` on the `dev_3.2_stats` branch.  I had followed the latest documentation to do the install, which wasn't working.  Once I went back and followed the v3.3.1 docs for the install it built successfully.  Thanks!

I've been attempting to mod these guns (http://amzn.com/B07JH3BP8C) with your system.  The hardware available is a little different, though - only one RGB LED used for team color, two simple red muzzle flash LEDs, reload button on bottom, etc.  I had to design a new PCB layout to fit where the old one went.  It's working pretty well so far, except for a couple errors I made with the schematic that will require a new board revision.

Xasin, 2020-01-06:
Glad to hear it's compiling now!

The fact that you made your own board for these guns is really awesome, by the way! If you have some pictures or similar I would love to see them.

If you want I could help you modify the code to have a changed number of LEDs along the body, or a different button input, but you seem to be managing well enough.

spectre3ooo, 2020-01-06:
Yeah, absolutely.  I'll upload some pics this evening.
Help on the LEDs and buttons would be greatly appreciated.  I'll update my fork with my changes and pics, and add issues to describe the LED/button functionality changes.

Side note, what speaker did you use?  The one that came in the guns is sounding somewhat overdriven.

spectre3ooo, 2020-01-08:
I haven't had a chance to clean up the code/schematics to update my fork, but I did throw some images up on imgur here: https://imgur.com/a/twxOzUD

Xasin, 2020-01-08:
@spectre3ooo Take your time setting things up, I'll be rather busy with some Uni stuff for the next two weeks sooo ...

It's best if you open an issue about this on your fork and @ me whenever you're ready.

spectre3ooo, 2020-01-08:
No problem.  School is definitely more important.

The existing speaker looks like a common 29mm diameter.  Would these work?  http://amzn.com/B07FMR5JGX

These look almost identical, though: http://amzn.com/B07M8ZZTJS

Xasin, 2020-01-08:
Anything that is 8 Ohms and less than 2W will be fine for the MAX driver IC, and needs no further adjustment either :)

Closed 2020-01-06.

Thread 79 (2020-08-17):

Question re: The PCB needs a redesign due to design flaws!

philippsandi, 2020-08-17:
Hey there,
very nice project :-)
I stumbled upon this caution above regarding the PCB and wanted to ask, if you could specify the existing design flaws?

Thanks and greetings,
Philipp

Xasin, 2020-08-17:
Ah, that might be because I still need to update the Aisler website!
I actually got through most of the redesign and tested a Revision 2 of the PCB, but due to my University getting busier I was so far unable to properly update things there.

The PCB is pretty much fully done, but if you are patient, I would like to give it a quick review in the next day or two to make sure I didn't forget anything :)

philippsandi, 2020-08-18:
Oh cool, thank you for the quick answer - I'm in no hurry, so I'll gladly wait for the Revision 2. :-)

Xasin, 2020-08-19:
No problem @philippsandi, it's always a pleasure to see people enjoying my work!

I went over the PCB files, and I think I was able to round everything off already, so I think it's safe to use the current design files. The main problems were with a button that... I no longer have anyways <.<'

I recommend ordering the boards off of Aisler or JLCPCB, depending on how many you need.
Usually I'd say Aisler is OK, but right now their BOM cost is REALLY messed up - it's telling me 2000€ for one set of electronics for my Lasertag system, which used to be 30€...

I have a Digikey parts list I can give you though:
https://hackaday.io/project/160804-lzrtag-flexible-diy-lasertag/files

Will this be sufficient?

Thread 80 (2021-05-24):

A bit lazy...

zwep, 2021-05-24:
Hi,

I am a little bit lazy/busy with other stuff, but would love to try this project out. Is there somewhere a pre-written `How-to` on how to use this repository? Which stuff to buy, and how to assemble everything?

If that is not the case, totally fine as well. But then I know that I could add something like that in the near future

Xasin, 2021-05-25:
Hi Zwep!
There isn't really a tutorial or similar for this right now.
The closest you can get is our write-up on HackADay found here: https://hackaday.io/project/160804-lzrtag-flexible-diy-lasertag

*However*, I would recommend waiting a little bit.
This project is due for a thorough clean-up, both in the code and hardware. If you can wait about half a year to a year, there will be a complete remake of most components to provide a much nicer base for people to work off of.

The current version works fine, but it has a few flaws and quirks that I'm not quite happy with.

I'll let you decide if you want to wait or build one now, but I recommend waiting a bit :)

Ps: If you'd like to do a "user-test" later on and help me make good tutorials for how to program and assemble these, I would absolutely love that.
I could add you as a collaborator to the HackADay or GitHub page so you're in the loop.

zwep, 2021-05-26:
Hi Xasin,

ah cool! Nice to hear :) I think I'll wait for now and see if I can help later on with any user-testing.

However, I am curious if you are going to change anything to the 3D printed case. I have a 3d printer at home which allows me to already assemble one casing for example :)

Greetings,
zwep

Xasin, 2021-05-26:
I actually wanted to do a complete redesign of the casing as well ^^

The new casing needs to include a proper mount for the speaker - the current version provides horrible sound, which is in part due to how I placed the speakers, and it's just such a shame.

It'd also be a lot bigger and offer more ways to mount more visually appealing LEDs, as well as a OLED display as heads-up-display and better buttons :>

You can still 3D print the current casing since it's not a lot of material, but I'd wait a bit.

The 3D printed case files should also be on HackADay

lucullusTheOnly, 2021-06-18:
Hi,

I've just found you at digital Maker Fair Hannover. Just as zwep I'm also in for user testing. In the past I tried to build such a system myself, though the overall structure lead into a deadlock, so I abandoned the project. Currently I don't have much time for contributing (my own projects filling much of the free time), but I will look further into your files. Maybe I can also contribute a bit.

Thanks for your work! I definitely will watch your progress :D

laserir, 2021-12-24:
Hey there! Hope everything is going well for you!

Mind to give us a quick update about the v4.0 hardware and software changes?

Xasin, 2021-12-30:
@laserir
Thanks for your interest!
As of right now, the project is still on hold for a few reasons:
- I'm focusing on my academic studies and am progressing through my master's thesis
- The component shortages have hit a lot of the vital elements I would normally use, including battery monitors etc.
- I'm waiting for the ESP32-S3 to be more widely available on DigiKey or a similar site.

I also have a few personal projects that take precedence, but I am hoping to start working on a newer version of the Hardware somewhen during the first half of 2022.
The list of changes I want to make has grown a little more, you can find it [here on HackADay](https://hackaday.io/project/160804-lzrtag-flexible-diy-lasertag/log/189364-current-progress-and-moving-forwards)

tmb088, 2022-03-24:
Is this software based on [https://openlasertag.org/language/en/what-is-openlasertag/](url)?

Xasin, 2022-03-24:
@tmb088 no, this entire ecosystem was written fully independently of any pre-existing Lasertag software.

I am fairly confident that the hardware can be adapted to other systems as well, as a lot of the core components are modular enough (though this might take some know-how)
But there is no compatibility built-in to my system as of now.

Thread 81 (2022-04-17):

OLED i2c support

A7F, 2022-04-17:
Hi, first thing first, awesome project!
I was wondering if this project does support i2c diplays. Asking because they are super cheap and they should also be easy to add into guns and eventually, rifles! They might display a bunch of information more efficiently rather than relying on haptic and light feedback.

Thank you once more for sharing! :)

Xasin, 2022-04-17:
Hi A7F!
Thanks for the question.

The ESP32 and my code library do have support for I2C OLED Panels, and I did, in fact, leave out a terminal connection that should be compatible with those cheap 128x32 OLED strip breakout boards you can find on eBay
The connector exposes power and I2C, so it works for all I2C OLED displays.

The code itself does not yet have a OLED panel integration, and I am rather busy with a new internship, so I am currently not actively maintaining the project.
However, adding support should be fairly easy - [you can find my OLED lib code here](https://github.com/XasWorks/XasCode/tree/master/ESP32/LittleOLED)
It's not the best OLED code and you can feel free to use something else, but it works well enough for some basic text and bitmap drawings.

In fact, I am aiming to add proper support for OLED Panels in the next big revision of the Lasertag project, perhaps even using transparent OLED panels as heads-up-display.
You could look through them to aim, they'd display a reticle as well as vital information!

Again, right now I am not in the right place to actively maintain it, and the component shortage is making it too volatile for me to commit to a new PCB revision since parts can be out of stock for extremely long times.
But I will eventually want to get back to this.

A7F, 2022-04-17:
amazing, thank you. I might give this project a shot (...got it? hehe), and eventually I might add this feature as I am planning to do everything with rifles instead of guns - they look more badass and give a "halo-like" feel.

Just one more question though: is it possible to also add an addressable 5V led strip instead of using embedded rgb leds?

Xasin, 2022-04-17:
Good luck!
I really hope that the parts for the project are in stock, otherwise it'll require a bit of adjusting. The main concern here is the battery charger, potentially stuff like the accellerometer and speaker IC, etc.

Also yes it absolutely is!
The internal LEDs are all WS2812 LEDs, and the board exposes the data line on the end connector towards the vest.
It should be very easy to chain extra LEDs on to this, and I think I even programmed the LED code so that it can handle arbitrary length LED strips... I am not sure about that though.

But TL;DR, yes. WS2812 LEDs are supported.

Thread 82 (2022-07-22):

Cloning the master branch recursively fails due to a missing submodule

InterstellarDrift, 2022-07-22:
Attatched is the relevant section of git output
```
git clone https://github.com/lzrtag/LZRTag --recursive

.....

Cloning into '$HOME/Programs/LZRTag/ESP32/Main/sounds/lzrtag-sfx'...
ERROR: Repository not found.
fatal: Could not read from remote repository.

Please make sure you have the correct access rights
and the repository exists.
fatal: clone of 'git@github.com:lzrtag/lzrtag-sfx.git' into submodule path '$HOME/Programs/LZRTag/ESP32/Main/sounds/lzrtag-sfx' failed
Failed to clone 'ESP32/Main/sounds/lzrtag-sfx'. Retry scheduled
Cloning into '$HOME/Programs/LZRTag/XasCode'...
remote: Enumerating objects: 5231, done.
remote: Counting objects: 100% (979/979), done.
remote: Compressing objects: 100% (574/574), done.
remote: Total 5231 (delta 501), reused 781 (delta 329), pack-reused 4252
Receiving objects: 100% (5231/5231), 3.42 MiB | 1.57 MiB/s, done.
Resolving deltas: 100% (2785/2785), done.
Cloning into '$HOME/Programs/LZRTag/ESP32/Main/sounds/lzrtag-sfx'...
ERROR: Repository not found.
fatal: Could not read from remote repository.

Please make sure you have the correct access rights
and the repository exists.
fatal: clone of 'git@github.com:lzrtag/lzrtag-sfx.git' into submodule path '$HOME/Programs/LZRTag/ESP32/Main/sounds/lzrtag-sfx' failed
Failed to clone 'ESP32/Main/sounds/lzrtag-sfx' a second time, `aborting`
```
Note: I edited the paths to hide my home directory.

I also searched Github for lzrtag-sfx and found nothing, is it possible this repository is private or was deleted accidentally?

Xasin, 2022-08-24:
Hi!

Sorry for the delayed response, I was busy with work ^^'

You're right, the directory lzrtag-sfx is private. It was meant to be only temporarily so, as I am using sound effects from a Unity asset package and am not sure if I can have it public.
However, since I am not providing the raw audio game files, I am merely providing "translated", lower quality, encoded files, purely to be used for the Lasertag project, I believe I can open the repository.

Give it another go at pulling!

InterstellarDrift, 2022-08-24:
Thanks! I recloned the repo and it succeeded. Now I'll see if this makes my set of boards work.

Closed 2022-08-24.

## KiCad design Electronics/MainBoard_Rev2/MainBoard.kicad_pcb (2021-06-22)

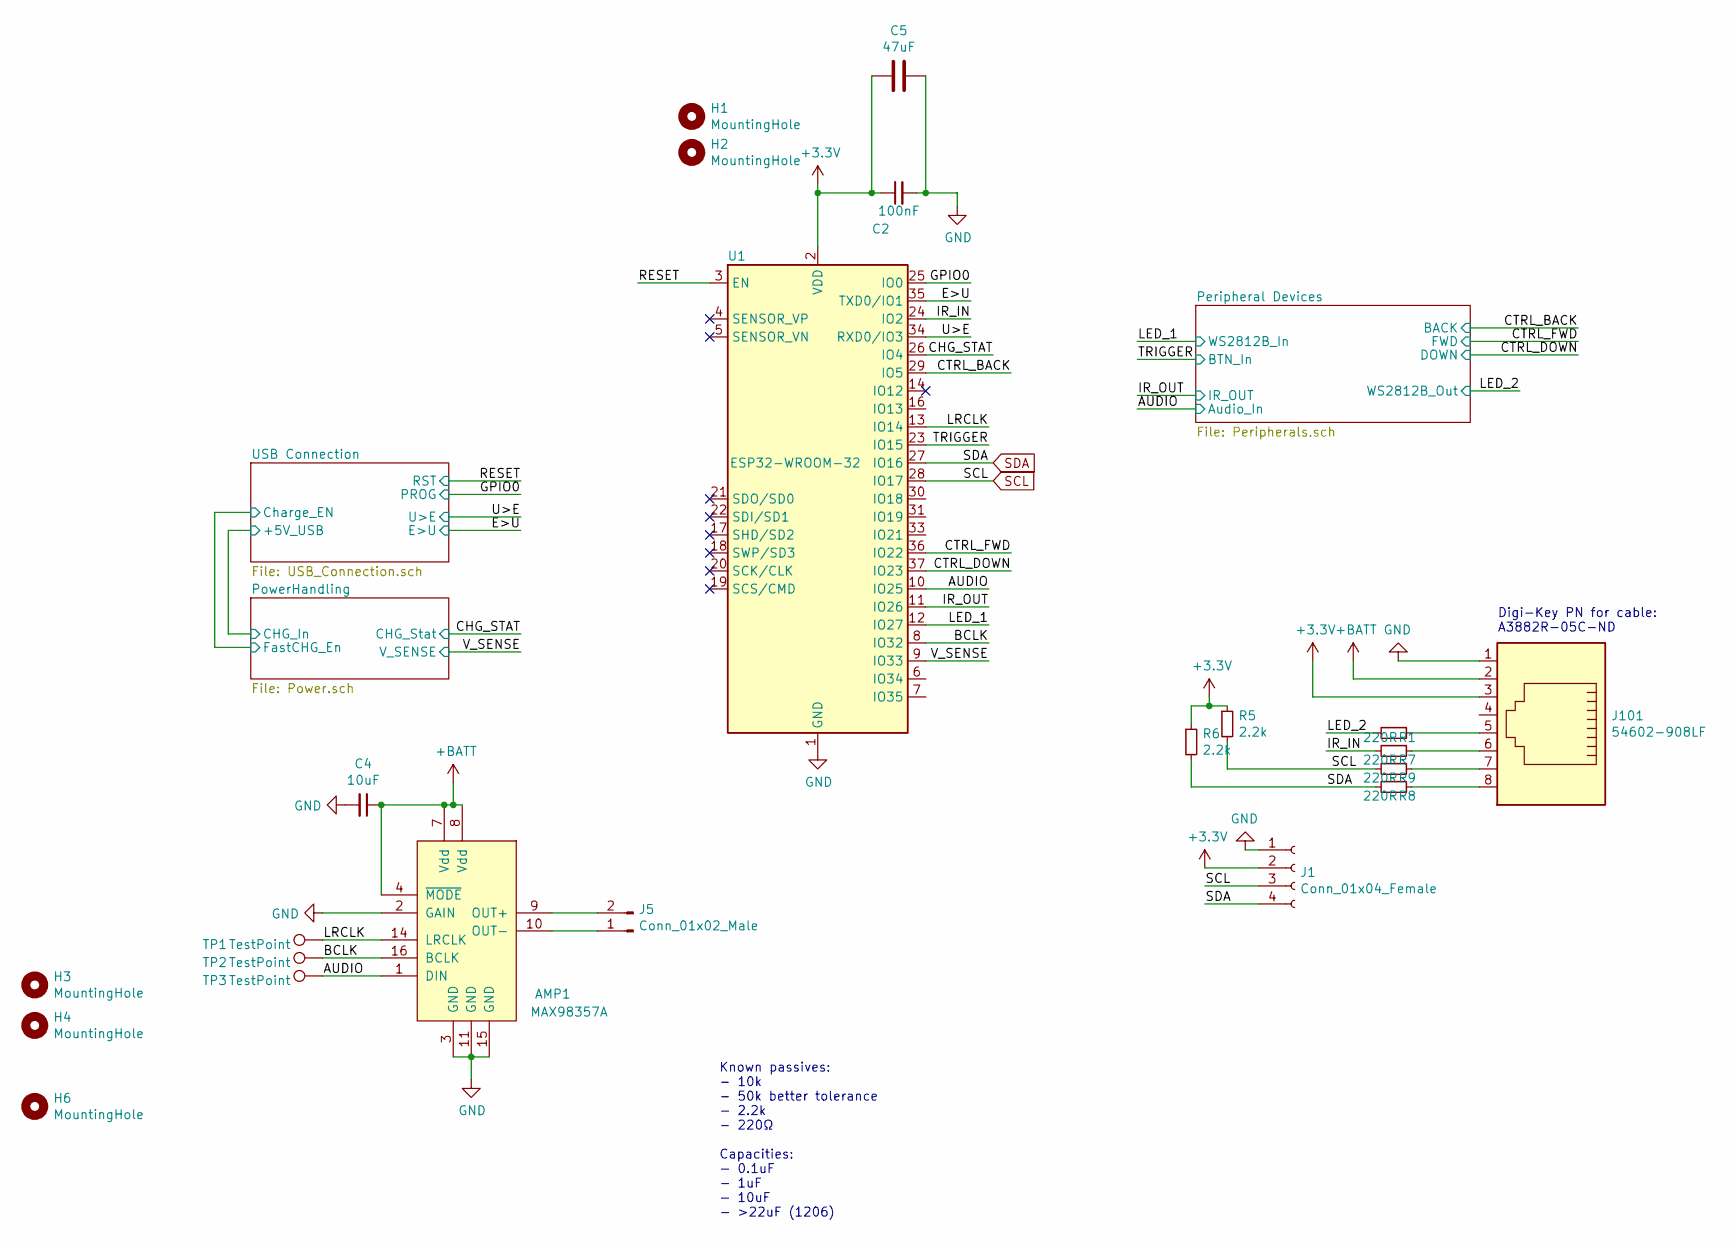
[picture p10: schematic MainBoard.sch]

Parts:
AMP1: MAX98357A; QFN-16-1EP_3x3mm_P0.5mm_EP2.7x2.7mm_ThermalVias; Digi-Key_PN MAX98357AETE+TCT-ND
C2: 100nF; C_0805_2012Metric
C4: 10uF; C_0805_2012Metric
C5: 47uF; C_1206_3216Metric
H1, H2: MountingHole; MountingHole_3.2mm_M3_DIN965
H3: MountingHole; KiCad-Logo_5mm_SolderMask
H4: MountingHole; OSHW-Logo_5.7x6mm_SilkScreen
H6: MountingHole; DragonIcon
J1: Conn_01x04_Female; PinSocket_1x04_P2.54mm_Vertical
J5: Conn_01x02_Male; PinHeader_1x02_P2.00mm_Vertical; Digi-Key_PN 668-1517-ND
J101: 54602-908LF; RJ45_Amphenol_54602-x08_Horizontal
R1, R7, R8, R9: 220R; R_0805_2012Metric
R5, R6: 2.2k; R_0805_2012Metric
TP1, TP2, TP3: TestPoint; TestPoint_Pad_2.0x2.0mm
U1: ESP32-WROOM-32; MPN ESP32-WROOM-32D (16MB); Digi-Key_PN 1904-1025-1-ND

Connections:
+3V3: C2.1, C5.2, J1.2, J101.3, R5.1, R6.1, U1.2 (VDD); also elsewhere on the board
+BATT: AMP1.4 (~MODE), AMP1.7 (Vdd), AMP1.8 (Vdd), C4.1, J101.2; also elsewhere on the board
/AUDIO: AMP1.1 (DIN), TP3.1, U1.10 (IO25)
/BCLK: AMP1.16 (BCLK), TP2.1, U1.8 (IO32)
/CHG_STAT: U1.26 (IO4); also elsewhere on the board
/CTRL_BACK: U1.29 (IO5); also elsewhere on the board
/CTRL_DOWN: U1.37 (IO23); also elsewhere on the board
/CTRL_FWD: U1.36 (IO22); also elsewhere on the board
/E>U: U1.35 (TXD0/IO1); also elsewhere on the board
/GPIO0: U1.25 (IO0); also elsewhere on the board
/IR_IN: R7.2, U1.24 (IO2)
/IR_OUT: U1.11 (IO26); also elsewhere on the board
/LED_1: U1.12 (IO27); also elsewhere on the board
/LED_2: R1.2; also elsewhere on the board
/LRCLK: AMP1.14 (LRCLK), TP1.1, U1.13 (IO14)
/RESET: U1.3 (EN); also elsewhere on the board
/TRIGGER: U1.23 (IO15); also elsewhere on the board
/U>E: U1.34 (RXD0/IO3); also elsewhere on the board
/V_SENSE: U1.9 (IO33); also elsewhere on the board
GND: AMP1.2 (GAIN), AMP1.3 (GND), AMP1.11 (GND), AMP1.15 (GND), C2.2, C4.2, C5.1, J1.1, J101.1, U1.1 (GND), U1.15 (GND), U1.38 (GND), U1.39 (GND); also elsewhere on the board
unnamed: AMP1.9 (OUT+), J5.2
unnamed: AMP1.10 (OUT-), J5.1
unnamed: J101.5, R1.1
unnamed: J101.6, R7.1
unnamed: J101.7, R9.1
unnamed: J101.8, R8.1
SCL: J1.3, R5.2, R9.2, U1.28 (IO17); also elsewhere on the board
SDA: J1.4, R6.2, R8.2, U1.27 (IO16); also elsewhere on the board

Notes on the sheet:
Known passives: - 10k - 50k better tolerance - 2.2k - 220Ω Capacities: - 0.1uF - 1uF - 10uF - >22uF (1206)
Digi-Key PN for cable: A3882R-05C-ND

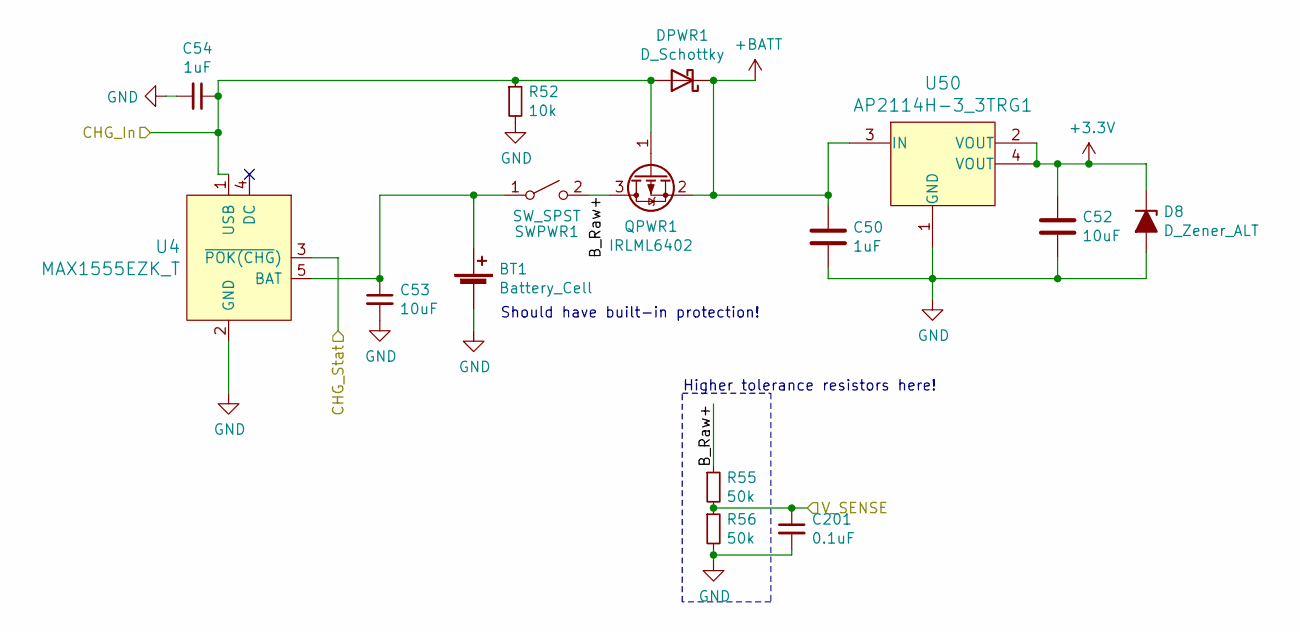
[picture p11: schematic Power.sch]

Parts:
BT1: Battery_Cell; PinHeader_1x02_P2.54mm_Horizontal; MPN S2B-PH-SM4-TB(LF)(SN); Digi-Key 455-1749-1-ND
C50, C54: 1uF; C_0805_2012Metric
C52, C53: 10uF; C_0805_2012Metric
C201: 0.1uF; C_0805_2012Metric
D8: D_Zener_ALT; D_SOD-123F; Digi-Key_PN F7701CT-ND
DPWR1: D_Schottky; D_0603_1608Metric; Digi-Key_PN CD0603-B0340RCT-ND
QPWR1: IRLML6402; SOT-23; MPN IRLML6402TRPBF; Digi-Key_PN IRLML6402PBFCT-ND
R52: 10k; R_0805_2012Metric
R55, R56: 50k; R_0805_2012Metric
SWPWR1: SW_SPST; PinHeader_1x02_P2.54mm_Vertical; Digi-Key_PN CKN9565-ND
U4: MAX1555EZK_T; SOT-753; MPN MAX1555EZK+T; Digi-Key_PN MAX1555EZK+TCT-ND
U50: AP2114H-3_3TRG1; SOT-223; MPN AP2114H-3.3TRG1; Digi-Key_PN AP2114H-3.3TRG1DICT-ND

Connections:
+3V3: C52.1, D8.1 (K), U50.2 (VOUT), U50.4 (VOUT); also elsewhere on the board
+BATT: C50.1, DPWR1.1 (K), QPWR1.2 (S), U50.3 (IN); also elsewhere on the board
/CHG_STAT: U4.3 (~POK(CHG)); also elsewhere on the board
/PowerHandling/B_Raw+: QPWR1.3 (D), R55.1, SWPWR1.2 (B)
/USB Connection/+5V_USB: C54.1, DPWR1.2 (A), QPWR1.1 (G), R52.1, U4.1 (USB); also elsewhere on the board
/V_SENSE: C201.1, R55.2, R56.1; also elsewhere on the board
GND: BT1.2 (-), C50.2, C52.2, C53.2, C54.2, C201.2, D8.2 (A), R52.2, R56.2, U4.2 (GND), U50.1 (GND); also elsewhere on the board
unnamed: BT1.1 (+), C53.1, SWPWR1.1 (A), U4.5 (BAT)

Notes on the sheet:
Should have built-in protection!
Higher tolerance resistors here!

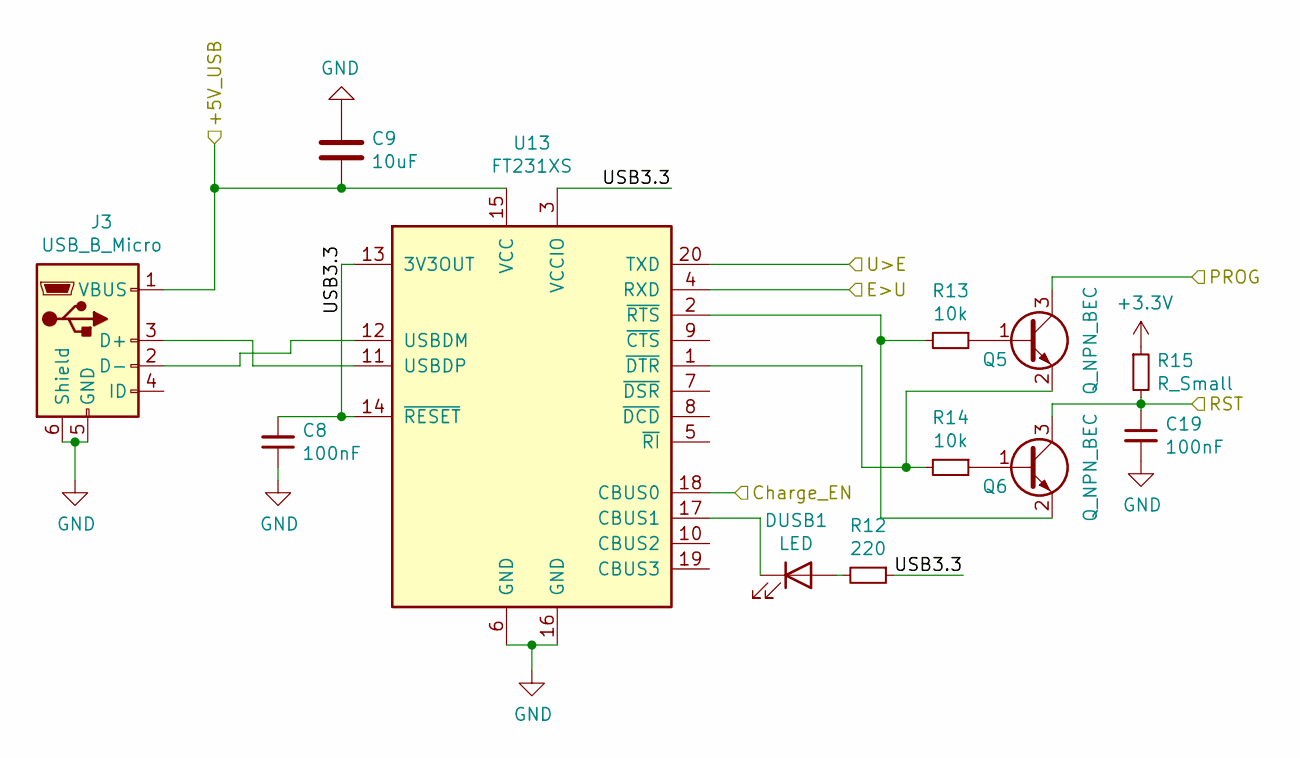
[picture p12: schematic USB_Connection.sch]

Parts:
C8, C19: 100nF; C_0805_2012Metric
C9: 10uF; C_0805_2012Metric
DUSB1: LED; LED_0805_2012Metric
J3: USB_B_Micro; USB_Micro-B_Wuerth_629105150521; Digi-Key_PN 732-5960-1-ND
Q5, Q6: Q_NPN_BEC; SOT-23; Digi-Key_PN 1727-2956-1-ND
R12: 220; R_0805_2012Metric
R13, R14: 10k; R_0805_2012Metric
R15: R_Small; R_0805_2012Metric
U13: FT231XS; SSOP-20_3.9x8.7mm_P0.635mm; Digi-Key_PN 768-1129-1-ND

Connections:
+3V3: R15.1; also elsewhere on the board
/E>U: U13.4 (RXD); also elsewhere on the board
/GPIO0: Q5.3 (C); also elsewhere on the board
/RESET: C19.1, Q6.3 (C), R15.2; also elsewhere on the board
/U>E: U13.20 (TXD); also elsewhere on the board
/USB Connection/+5V_USB: C9.2, J3.1 (VBUS), U13.15 (VCC); also elsewhere on the board
/USB Connection/Charge_EN: U13.18 (CBUS0)
/USB Connection/USB3.3: C8.2, R12.1, U13.3 (VCCIO), U13.13 (3V3OUT), U13.14 (~RESET)
GND: C8.1, C9.1, C19.2, J3.5 (GND), J3.6 (Shield), U13.6 (GND), U13.16 (GND); also elsewhere on the board
unnamed: DUSB1.1 (K), U13.17 (CBUS1)
unnamed: DUSB1.2 (A), R12.2
unnamed: J3.2 (D-), U13.12 (USBDM)
unnamed: J3.3 (D+), U13.11 (USBDP)
unnamed: Q5.1 (B), R13.1
unnamed: Q5.2 (E), R14.2, U13.1 (~DTR)
unnamed: Q6.1 (B), R14.1
unnamed: Q6.2 (E), R13.2, U13.2 (~RTS)

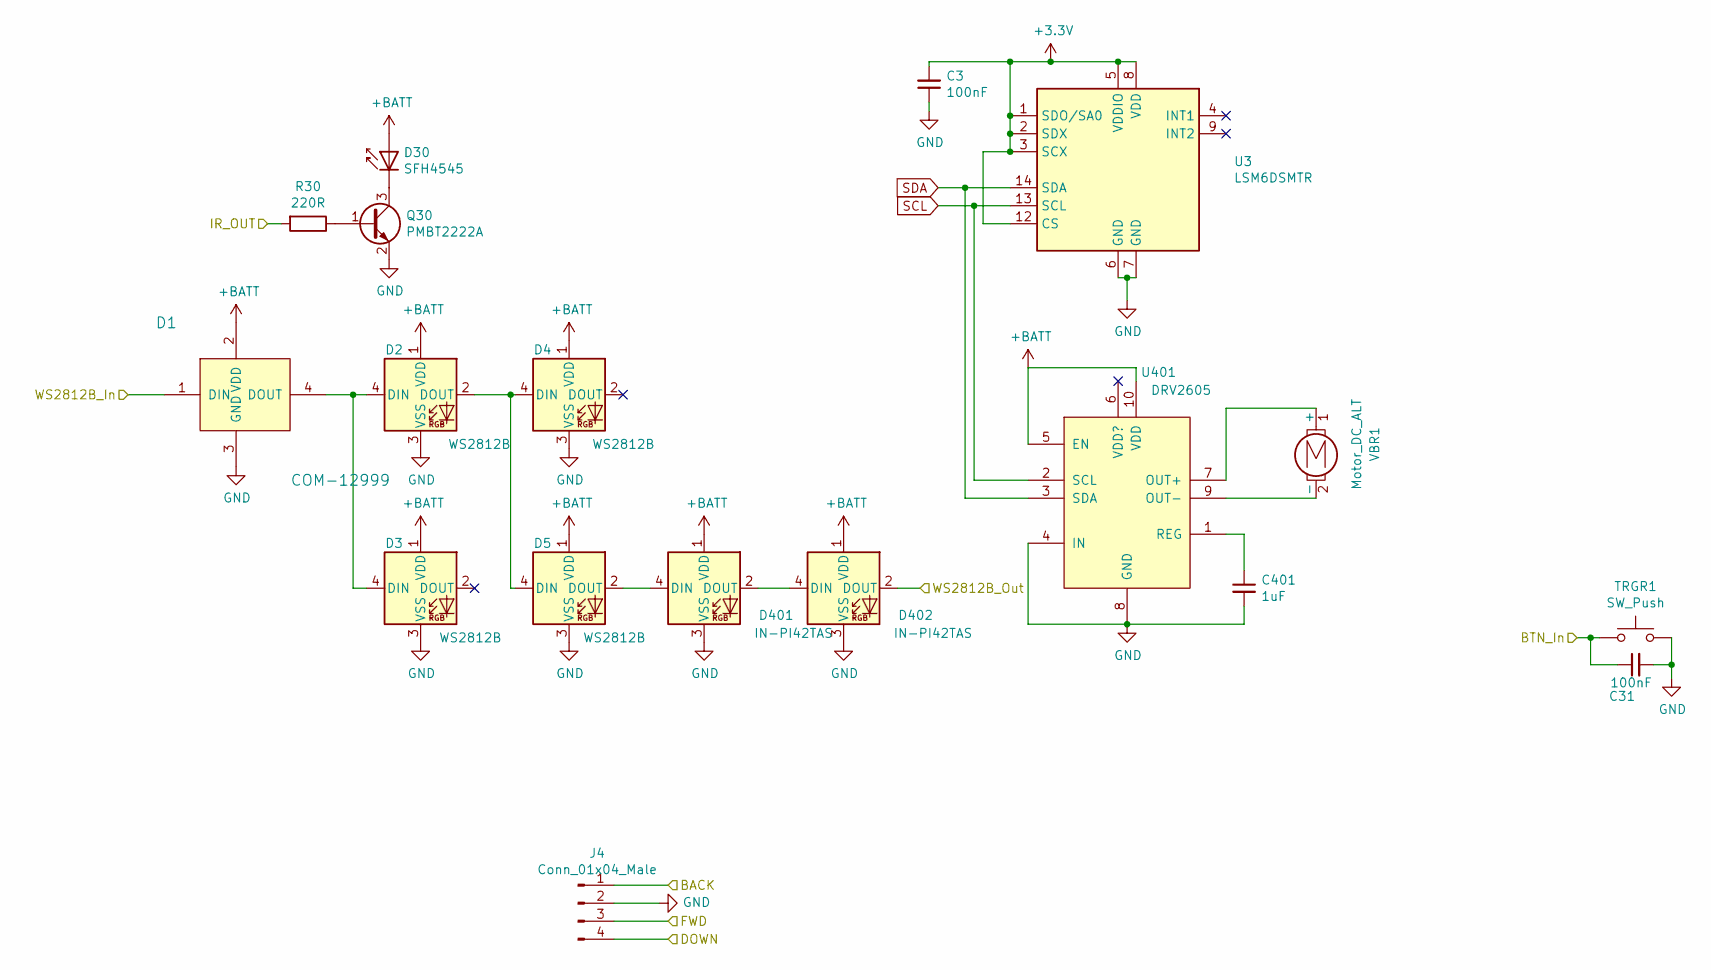
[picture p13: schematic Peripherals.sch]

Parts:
C3, C31: 100nF; C_0805_2012Metric
C401: 1uF; C_0805_2012Metric
D1: COM-12999; PinHeader_1x04_P2.00mm_Vertical; MPN COM-12999; Digi-Key_PN 1568-1214-ND
D2: WS2812B; LED_WS2812B_PLCC4_5.0x5.0mm_P3.2mm; Digi-Key_PN 1528-1104-ND
D3, D4, D5: WS2812B; LED_WS2812B_PLCC4_5.0x5.0mm_P3.2mm
D30: SFH4545; PinHeader_1x02_P2.00mm_Vertical; MPN SFH 4346; Digi-Key_PN 475-3581-ND
D401, D402: IN-PI42TAS
J4: Conn_01x04_Male; nav_switch_COM_08184; Digi-Key_PN 1568-1827-ND
Q30: PMBT2222A; SOT-23; Digi-Key_PN 1727-2956-1-ND
R30: 220R; R_0805_2012Metric
TRGR1: SW_Push; PinHeader_1x02_P2.54mm_Vertical; Digi-Key_PN EG1701-ND
U3: LSM6DSMTR; LGA-14_3x2.5mm_P0.5mm_LayoutBorder3x4y; Digi-Key_PN 497-15383-1-ND
U401: DRV2605; VSSOP-10_3x3mm_P0.5mm
VBR1: Motor_DC_ALT; PinHeader_1x02_P2.54mm_Vertical; MPN 316040001; Digi-Key_PN 1597-1244-ND

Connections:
+3V3: C3.2, U3.1 (SDO/SA0), U3.2 (SDX), U3.3 (SCX), U3.5 (VDDIO), U3.8 (VDD), U3.12 (CS); also elsewhere on the board
+BATT: D1.2 (VDD), D2.1 (VDD), D3.1 (VDD), D4.1 (VDD), D5.1 (VDD), D30.2 (A), D401.1 (VDD), D402.1 (VDD), U401.5 (EN), U401.10 (VDD); also elsewhere on the board
/CTRL_BACK: J4.1; also elsewhere on the board
/CTRL_DOWN: J4.4; also elsewhere on the board
/CTRL_FWD: J4.3; also elsewhere on the board
/IR_OUT: R30.2; also elsewhere on the board
/LED_1: D1.1 (DIN); also elsewhere on the board
/LED_2: D402.2 (DOUT); also elsewhere on the board
/TRIGGER: C31.1, TRGR1.1; also elsewhere on the board
GND: C3.1, C31.2, C401.2, D1.3 (GND), D2.3 (VSS), D3.3 (VSS), D4.3 (VSS), D5.3 (VSS), D401.3 (VSS), D402.3 (VSS), J4.2, Q30.2 (E), TRGR1.2, U3.6 (GND), U3.7 (GND), U401.4 (IN), U401.8 (GND); also elsewhere on the board
unnamed: C401.1, U401.1 (REG)
unnamed: D1.4 (DOUT), D2.4 (DIN), D3.4 (DIN)
unnamed: D2.2 (DOUT), D4.4 (DIN), D5.4 (DIN)
unnamed: D30.1 (K), Q30.3 (C)
unnamed: D401.2 (DOUT), D402.4 (DIN)
unnamed: D5.2 (DOUT), D401.4 (DIN)
unnamed: Q30.1 (B), R30.1
unnamed: U401.7 (OUT+), VBR1.1 (+)
unnamed: U401.9 (OUT-), VBR1.2 (-)
SCL: U3.13 (SCL), U401.2 (SCL); also elsewhere on the board
SDA: U3.14 (SDA), U401.3 (SDA); also elsewhere on the board

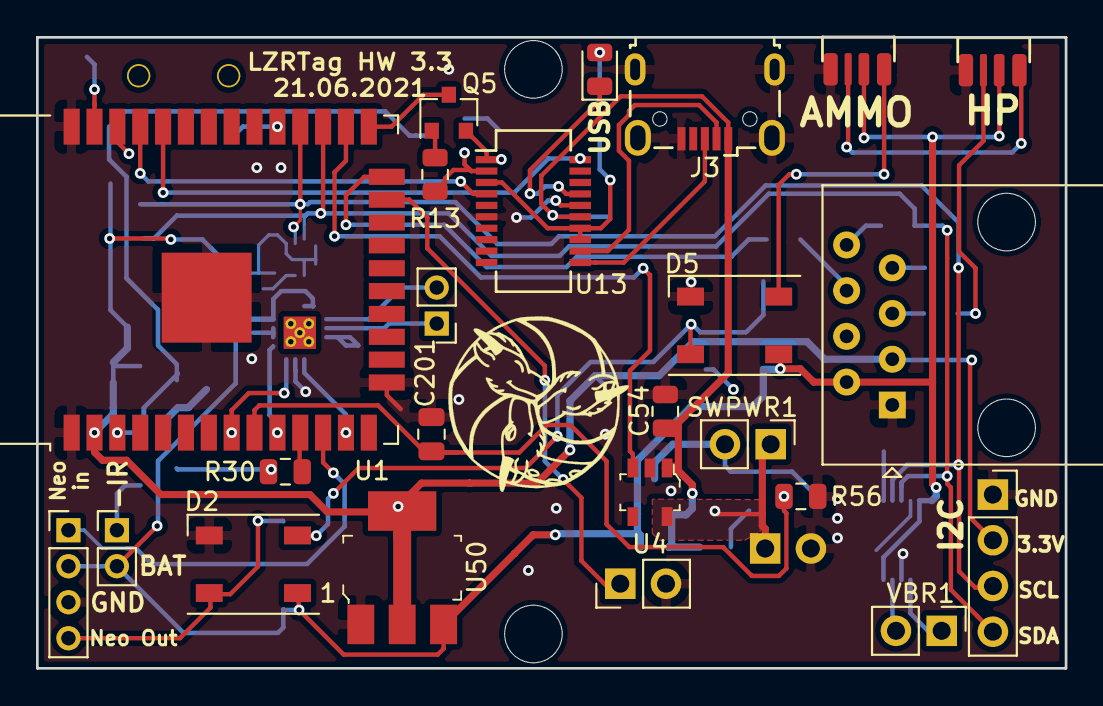
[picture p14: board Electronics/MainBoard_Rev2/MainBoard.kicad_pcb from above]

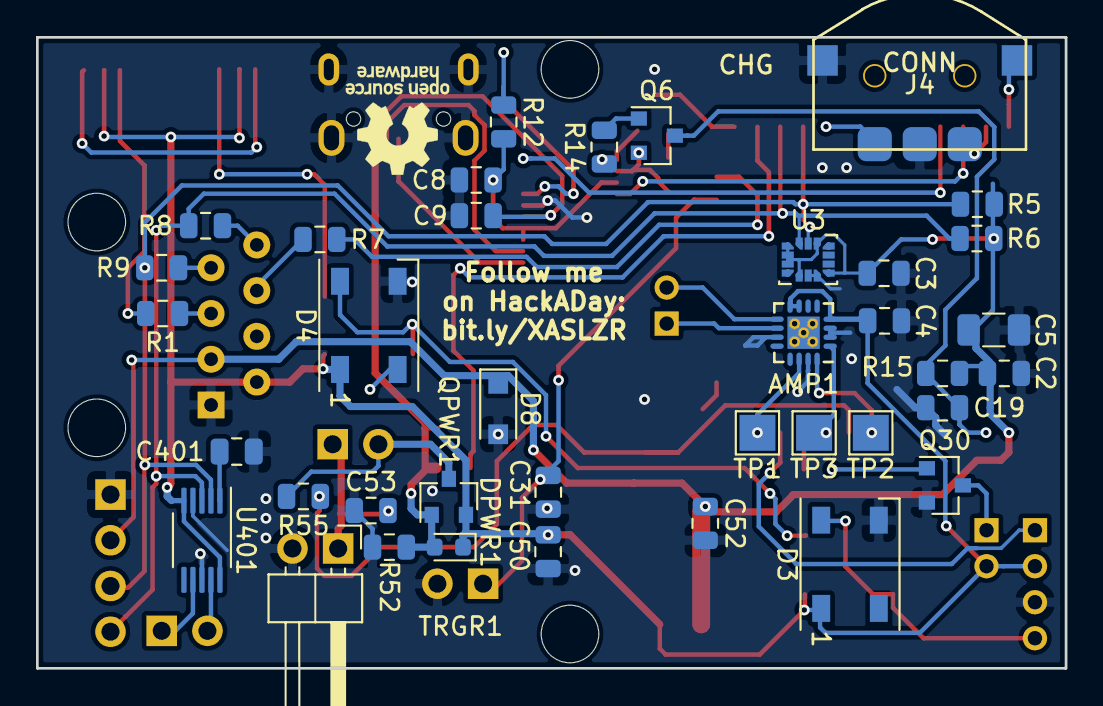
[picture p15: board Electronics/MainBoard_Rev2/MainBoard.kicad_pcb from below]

Board: 2 copper layers, 57.2 x 35.1 mm, 67 parts (40 on the bottom side), 49 nets.

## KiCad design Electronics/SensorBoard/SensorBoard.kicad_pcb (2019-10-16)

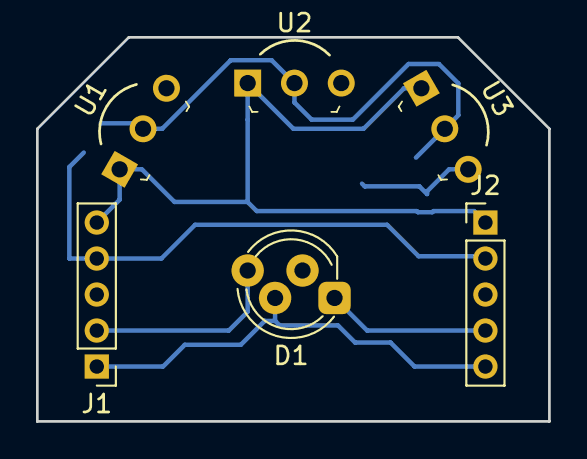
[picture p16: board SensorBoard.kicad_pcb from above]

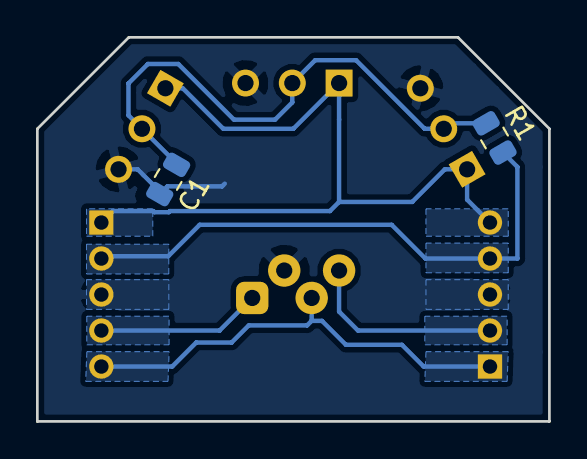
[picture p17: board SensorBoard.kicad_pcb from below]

Board: 2 copper layers, 28.4 x 21.3 mm, 8 parts (2 on the bottom side), 7 nets.

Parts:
C1: C_Small; C_0805_2012Metric
D1: NeoPixel_THT; LED_D5.0mm-4_RGB_Staggered_Pins
J1, J2: Conn_01x05_Male; PinHeader_1x05_P2.00mm_Vertical
R1: R_Small; R_0805_2012Metric
U1, U2, U3: TSSP58038; TO-92-3_Formed_Leads

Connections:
+3V3: J1.4, J2.2, R1.2
+BATT: D1.3, J1.1, J2.5
GND: C1.2, D1.2, J1.3, J2.3, U1.3, U2.3, U3.3
unnamed: C1.1, R1.1, U1.2, U2.2, U3.2
unnamed: D1.1, J2.4
unnamed: D1.4, J1.2
unnamed: J1.5, J2.1, U1.1, U2.1, U3.1

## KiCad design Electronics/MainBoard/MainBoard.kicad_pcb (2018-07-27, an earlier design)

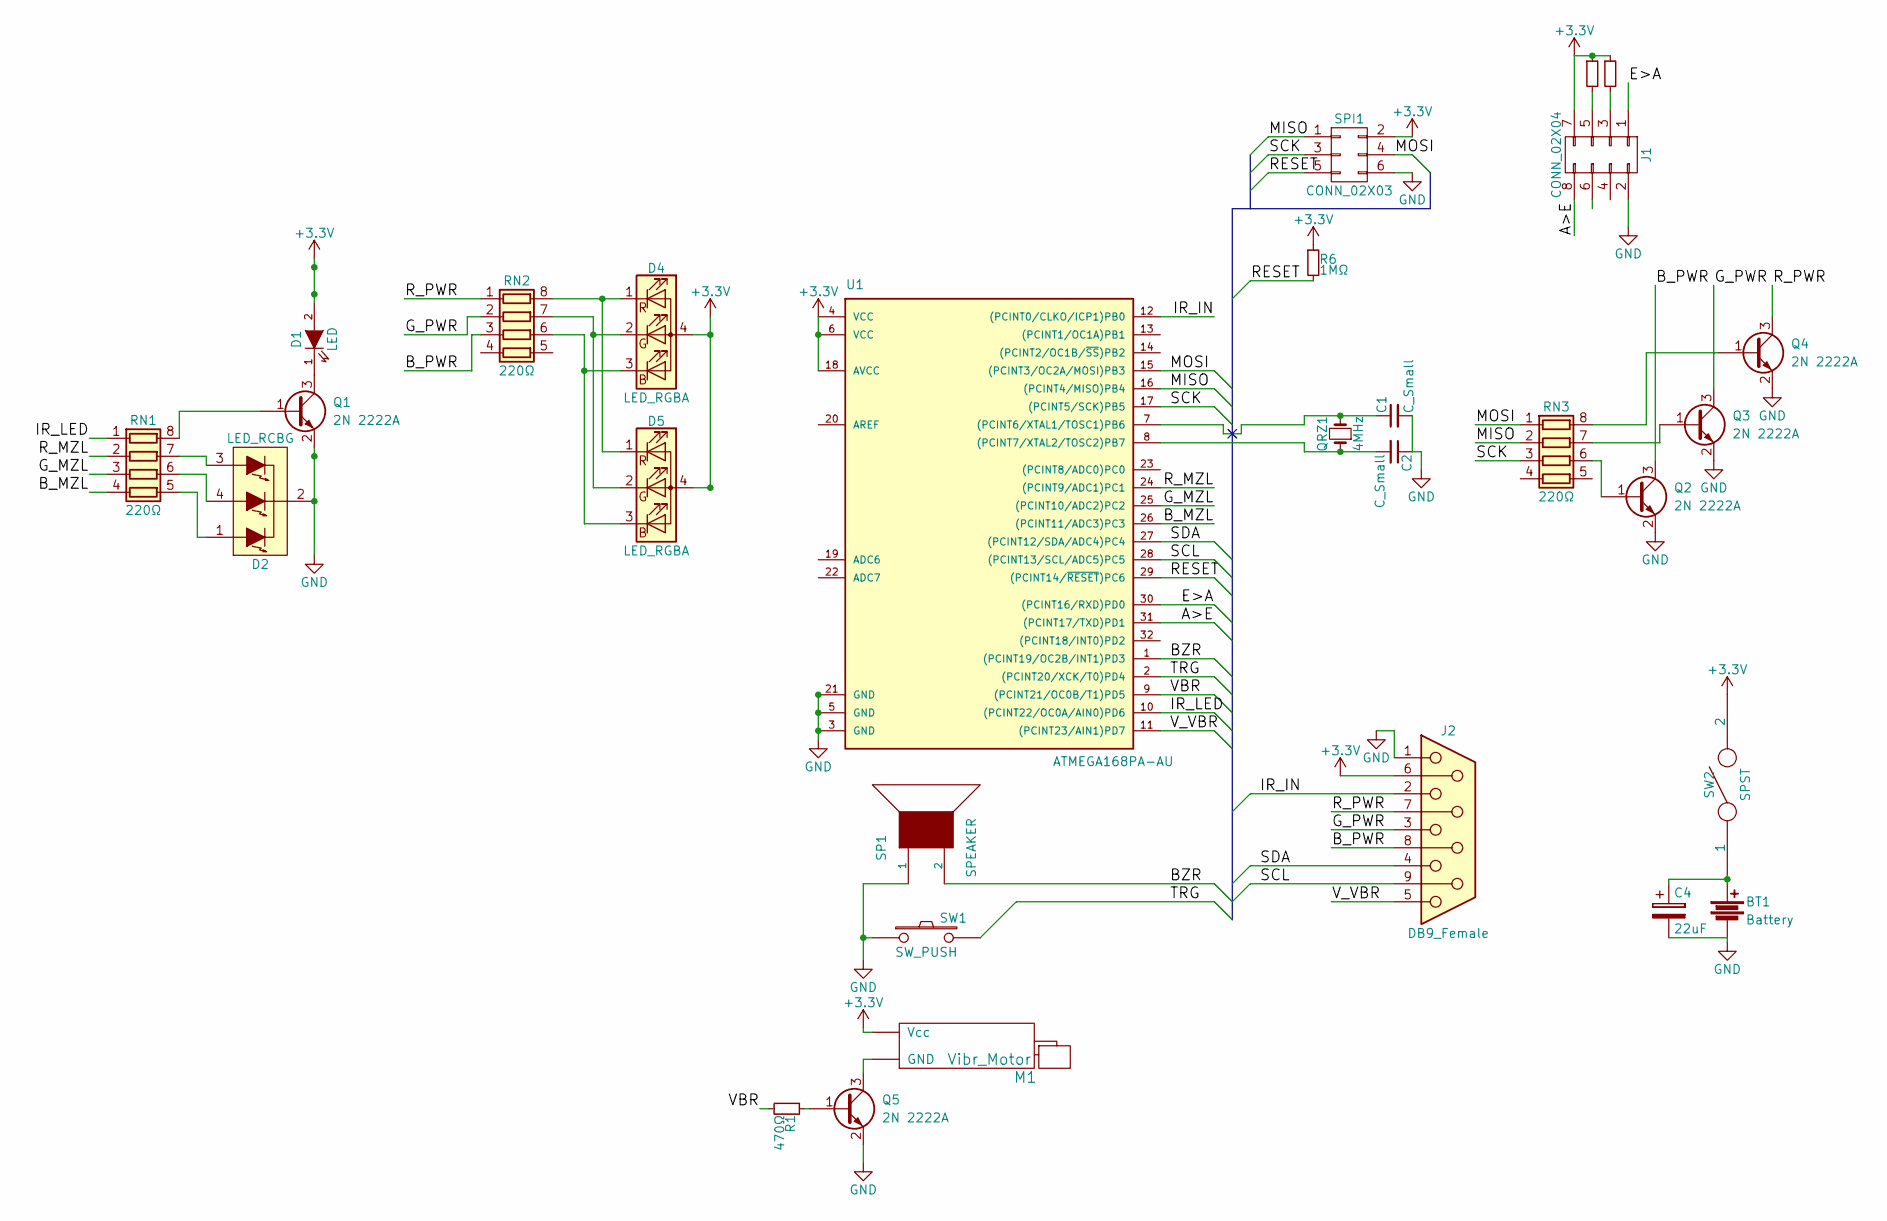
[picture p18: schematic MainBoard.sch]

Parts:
BT1: Battery; JST_PH_B2B-PH-K_02x2.00mm_Straight
C1, C2: C_Small; C_0603_HandSoldering
C4: 22uF; CP_Elec_5x5.3
D1: LED; LED_D3.0mm_Horizontal_O1.27mm_Z10.0mm
D2: LED_RCBG; LED_D5.0mm-4
D4, D5: LED_RGBA; LED_Cree-PLCC4_3.2x2.8mm_CCW
J1: CONN_02X04; Pin_Header_Straight_2x04_Pitch2.54mm
J2: DB9_Female; DSUB-9_Female_Horizontal_Pitch2.77x2.84mm_EdgePinOffset4.94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
M1: Vibr_Motor; Pin_Header_Straight_1x02_Pitch2.54mm
Q1, Q2, Q3, Q4, Q5: 2N 2222A; SOT-23_Handsoldering
QRZ1: 4MHz; Crystal_HC49-U_Vertical
R1: 470Ω; R_0603_HandSoldering
R6: 1MΩ; R_0603_HandSoldering
R9, R11: RST; R_0603_HandSoldering
RN1, RN2, RN3: 220Ω; R_Array_Convex_4x0603
SP1: SPEAKER; Buzzer_15x7.5RM7.6
SPI1: CONN_02X03; Pin_Header_Straight_2x03_Pitch2.54mm
SW1: SW_PUSH; Pin_Header_Straight_1x02_Pitch2.54mm
SW2: SPST; Pin_Header_Straight_1x03_Pitch2.54mm
U1: ATMEGA168PA-AU; TQFP-32_7x7mm_Pitch0.8mm

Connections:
+3V3: D1.2 (A), D4.4 (A), D5.4 (A), J1.7, J2.6, M1.2 (Vcc), R6.1, R9.1, R11.1, SPI1.2, SW2.2, U1.4 (VCC), U1.6 (VCC), U1.18 (AVCC)
/A>E: J1.8, U1.31 ((PCINT17/TXD)PD1)
/BZR: SP1.2, U1.1 ((PCINT19/OC2B/INT1)PD3)
/B_MZL: RN1.4 (R4.1), U1.26 ((PCINT11/ADC3)PC3)
/B_PWR: J2.8, Q2.3 (C), RN2.3 (R3.1)
/E>A: J1.1, U1.30 ((PCINT16/RXD)PD0)
/G_MZL: RN1.3 (R3.1), U1.25 ((PCINT10/ADC2)PC2)
/G_PWR: J2.3, Q3.3 (C), RN2.2 (R2.1)
/IR_IN: J2.2, U1.12 ((PCINT0/CLKO/ICP1)PB0)
/IR_LED: RN1.1 (R1.1), U1.10 ((PCINT22/OC0A/AIN0)PD6)
/MISO: RN3.2 (R2.1), SPI1.1, U1.16 ((PCINT4/MISO)PB4)
/MOSI: RN3.1 (R1.1), SPI1.4, U1.15 ((PCINT3/OC2A/MOSI)PB3)
/RESET: R6.2, SPI1.5, U1.29 ((PCINT14/~RESET~)PC6)
/R_MZL: RN1.2 (R2.1), U1.24 ((PCINT9/ADC1)PC1)
/R_PWR: J2.7, Q4.3 (C), RN2.1 (R1.1)
/SCK: RN3.3 (R3.1), SPI1.3, U1.17 ((PCINT5/SCK)PB5)
/SCL: J2.9, U1.28 ((PCINT13/SCL/ADC5)PC5)
/SDA: J2.4, U1.27 ((PCINT12/SDA/ADC4)PC4)
/TRG: SW1.2, U1.2 ((PCINT20/XCK/T0)PD4)
/VBR: R1.2, U1.9 ((PCINT21/OC0B/T1)PD5)
/V_VBR: J2.5, U1.11 ((PCINT23/AIN1)PD7)
GND: BT1.2, C1.2, C2.1, C4.2, D2.2 (COMMON_CATHODE), J1.2, J2.1, Q1.2 (E), Q2.2 (E), Q3.2 (E), Q4.2 (E), Q5.2 (E), SP1.1, SPI1.6, SW1.1, U1.3 (GND), U1.5 (GND), U1.21 (GND)
unnamed: BT1.1, C4.1, SW2.1
unnamed: C1.1, QRZ1.2, U1.7 ((PCINT6/XTAL1/TOSC1)PB6)
unnamed: C2.2, QRZ1.1, U1.8 ((PCINT7/XTAL2/TOSC2)PB7)
unnamed: D1.1 (K), Q1.3 (C)
unnamed: D2.1 (RED_ANODE), RN1.5 (R4.2)
unnamed: D2.3 (BLUE_ANODE), RN1.7 (R2.2)
unnamed: D2.4 (GREEN_ANODE), RN1.6 (R3.2)
unnamed: D4.1 (RK), D5.1 (RK), RN2.8 (R1.2)
unnamed: D4.2 (GK), D5.2 (GK), RN2.7 (R2.2)
unnamed: D4.3 (BK), D5.3 (BK), RN2.6 (R3.2)
unnamed: J1.3, R11.2
unnamed: J1.5, R9.2
unnamed: M1.1 (GND), Q5.3 (C)
unnamed: Q1.1 (B), RN1.8 (R1.2)
unnamed: Q2.1 (B), RN3.6 (R3.2)
unnamed: Q3.1 (B), RN3.7 (R2.2)
unnamed: Q4.1 (B), RN3.8 (R1.2)
unnamed: Q5.1 (B), R1.1

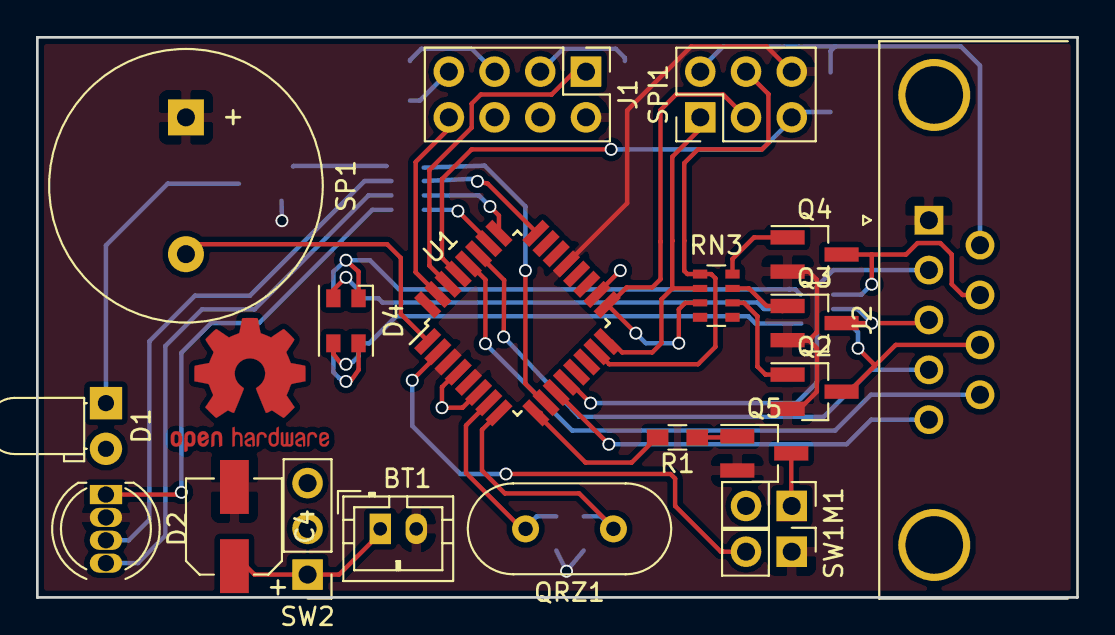
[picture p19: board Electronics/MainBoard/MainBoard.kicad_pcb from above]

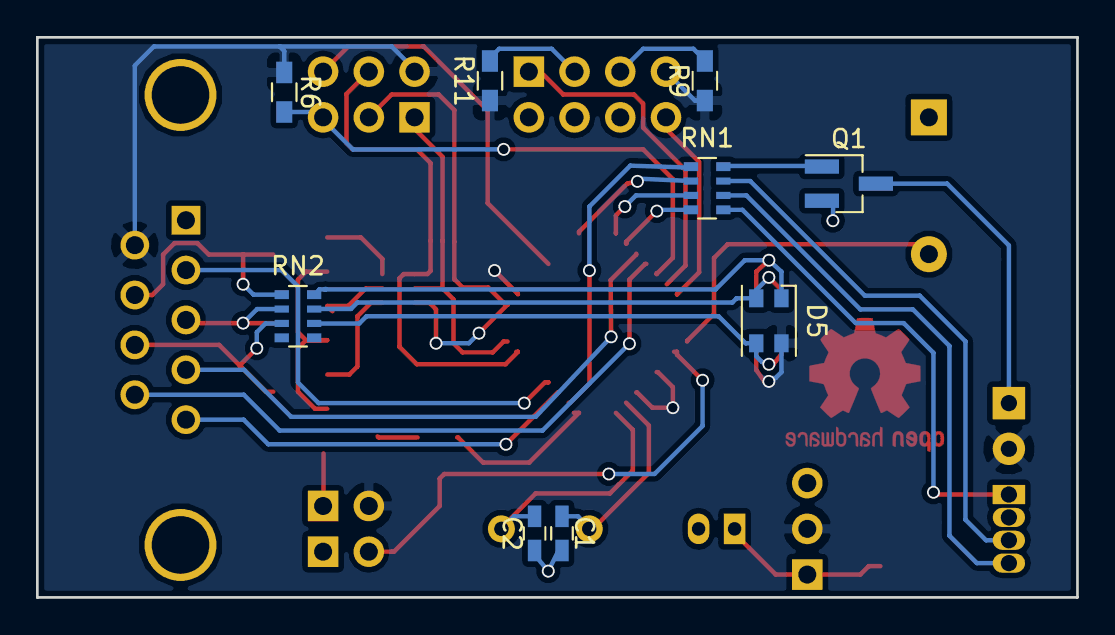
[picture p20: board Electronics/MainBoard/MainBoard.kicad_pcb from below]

Board: 2 copper layers, 57.8 x 31.1 mm, 29 parts (9 on the bottom side), 40 nets.

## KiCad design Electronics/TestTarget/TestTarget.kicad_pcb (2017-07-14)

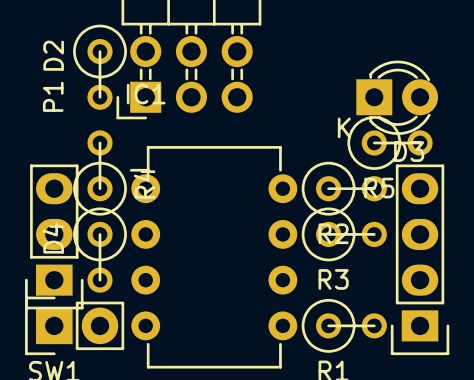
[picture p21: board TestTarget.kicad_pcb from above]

Board: 2 copper layers, 13 parts (0 on the bottom side), 13 nets, no tracks yet.

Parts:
BT1: Battery; Pin_Header_Straight_1x02
D1: LED_RCBG; Pin_Header_Straight_1x04
D2, D4: D; R1
D3: LED-G; LED-3MM
IC1: ATTINY13A-P; DIP-8_W7.62mm
P1: CONN_02X03; Pin_Header_Angled_2x03
R1, R2, R3: 470Ω; R1
R4: 1MΩ; R1
R5: 5KΩ; R1
SW1: SPST; Pin_Header_Straight_1x03

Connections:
+3V3: D2.2, D4.1, IC1.8, R4.2, R5.1
/MISO/G: IC1.6, P1.1, R2.1
/MOSI/R: IC1.5, P1.4, R3.1
/SCK/B: IC1.7, P1.3, R1.1
GND: BT1.2, D1.2, D3.1, IC1.4, P1.6
unnamed: BT1.1, SW1.1
unnamed: D1.1, R1.2
unnamed: D1.3, R3.2
unnamed: D1.4, R2.2
unnamed: D2.1, P1.2
unnamed: D3.2, R5.2
unnamed: D4.2, SW1.2
unnamed: IC1.1, R4.1

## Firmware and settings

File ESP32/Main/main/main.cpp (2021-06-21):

/*
 * main.cpp
 *
 *  Refined on: 10.05.2019
 *      Author: xasin
 *
 *  Enjoy the nerdness!
 */

#include <stdio.h>
#include <cmath>

#include "freertos/FreeRTOS.h"
#include "freertos/task.h"
#include "esp_system.h"
#include "esp_spi_flash.h"
#include "nvs_flash.h"
#include "esp_event_loop.h"

#include "esp_log.h"

#include "core/setup.h"

#include "fx/animatorThread.h"

#include <xnm/net_helpers.h>

#include "test.h"

using namespace Xasin::NeoController;

esp_err_t event_handler(void *context, system_event_t *event) {
	Xasin::MQTT::Handler::try_wifi_reconnect(event);

	LZR::mqtt.wifi_handler(event);

	return ESP_OK;
}

extern "C"
void app_main()
{
    nvs_flash_init();
    //esp_sleep_pd_config(ESP_PD_DOMAIN_RTC_PERIPH, ESP_PD_OPTION_ON);
    //esp_sleep_pd_config(ESP_PD_DOMAIN_XTAL, ESP_PD_OPTION_ON);

    tcpip_adapter_init();

    esp_event_loop_init(event_handler, 0);

    LZR::setup();

    XNM::NetHelpers::init_global_r3_ca();
    XNM::NetHelpers::set_mqtt(LZR::mqtt);

    XNM::NetHelpers::init();

    while(true) {
		 vTaskDelay(10*600);
    }

    fflush(stdout);
    esp_restart();
}

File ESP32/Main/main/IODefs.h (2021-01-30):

/*
 * IODefs.h
 *
 *  Created on: 7 Jan 2019
 *      Author: xasin
 */

#ifndef MAIN_IODEFS_H_
#define MAIN_IODEFS_H_

#define PIN_I2C_SDA GPIO_NUM_16
#define PIN_I2C_SCL GPIO_NUM_17

#define PIN_IR_OUT	GPIO_NUM_26
#define PIN_IR_IN	GPIO_NUM_2

#define PIN_I2S_DATA GPIO_NUM_25
#define PIN_I2S_BLCK GPIO_NUM_32
#define PIN_I2S_LRCK GPIO_NUM_14

#define PIN_VBRT	GPIO_NUM_13

#define PIN_TRIGR	GPIO_NUM_15

#define PIN_BAT_MES 	GPIO_NUM_33
#define ADC_BAT_MES		ADC1_CHANNEL_5
#define PIN_BAT_CHGING	GPIO_NUM_4

#define PIN_WS2812_OUT	GPIO_NUM_27
#define WS2812_NUMBER 	4

#define PIN_BAT_GREEN	GPIO_NUM_19
#define PIN_BAT_RED		GPIO_NUM_18

#define PIN_CONN_IND	GPIO_NUM_21

#define PIN_CTRL_FWD	GPIO_NUM_22
#define PIN_CTRL_BACK	GPIO_NUM_5
#define PIN_CTRL_DOWN	GPIO_NUM_23

#endif /* MAIN_IODEFS_H_ */

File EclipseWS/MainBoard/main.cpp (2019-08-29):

/*
 * main.cpp
 *
 *  Created on: May 9, 2016
 *      Author: xasin
 */


#include <avr/io.h>
#include <avr/interrupt.h>
#include <util/delay.h>

#include "Libcode/TIMER/Timer0.h"
#include "Localcode/Board/Board.h"

#include "Localcode/Connector.h"

#include "Localcode/Game/Player.h"

#include "Localcode/IRComs/IR_RX.h"
#include "Localcode/IRComs/IR_TX.h"

#include "Libcode/Communication/ESPUart/ESPUART.h"

volatile bool hasBeenShot = false;

uint8_t playerID = 255;

ESPComs::Endpoint PlayerIDEP(100, &playerID, 1, 0);

ESPComs::Endpoint ColorEP(101, &Board::Vest::team, 1, 0);
ESPComs::Endpoint VestBrightnessEP(200, &Board::Vest::mode, 1, 0);
ESPComs::Endpoint BrightnessOverrideEp(12, &Board::Vest::overrides, 3, 0);

struct BuzzCommand {
	uint16_t length;
	uint16_t startFreq;
	uint16_t endFreq;
};
void playPing() {
	BuzzCommand buzzCommand = *reinterpret_cast<BuzzCommand*>(&ESPComs::Endpoint::pubBuffer);

	Board::Buzzer::sweep(buzzCommand.startFreq, buzzCommand.endFreq, buzzCommand.length);
}
ESPComs::Endpoint PingEndpoint(11, &ESPComs::Endpoint::pubBuffer, 6, playPing);

void playVibration() {
	Board::Vibrator::vibrate(*(uint16_t *)&ESPComs::Endpoint::pubBuffer);
}
ESPComs::Endpoint VibrationEP(10, &ESPComs::Endpoint::pubBuffer, 2, playVibration);
void setVibrationMode() {
	Board::Vibrator::patternTiming = 0;
}
ESPComs::Endpoint VibrationPatternEP(110, &Board::Vibrator::patternMode, 1, setVibrationMode);


uint8_t currentShotID = 1;
void handleShots() {
	if(ESPComs::Endpoint::pubBuffer[0] == 0) {
		Board::Vibrator::vibrate(200);
		Board::Nozzle::flash(Board::Vest::team << 1);
		Board::Buzzer::sweep(3000, 1000, 150);
		IR::TX::startTX({playerID, currentShotID++});
		if(currentShotID == 16)
			currentShotID = 8;
	}
}
ESPComs::Endpoint ShootCommandEP(0, &ESPComs::Endpoint::pubBuffer, 1, handleShots);

IR::ShotPacket recShotData = {15, 15};
ESPComs::Source HitDetectSRC(1, &recShotData, 2);
void IRRXCB(IR::ShotPacket data) {
	if(data.playerID == playerID)
		return;
	recShotData = data;
	HitDetectSRC.fire();
}

int main() {
	DDRD 	|= 0b11;
	PORTD 	|= 0b11;

	Connector::init();

	_delay_ms(1500);
	ESPComs::init();
	ESPComs::onReset(Board::reset);

	Board::Vest::mode = 2;
	Board::Vest::team = 5;

	IR::RX::setCallback(IRRXCB);

	while(true) {
	}
	return 0;
}

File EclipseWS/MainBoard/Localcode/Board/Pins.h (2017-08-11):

/*
 * Pins.h
 *
 *  Created on: 23.05.2016
 *      Author: xasin
 */

#ifndef LOCALCODE_BOARD_PINS_H_
#define LOCALCODE_BOARD_PINS_H_

#define PROTOTYPE_1_BOARD

#ifdef PROTOTYPE_1_BOARD

#define TRIGGER_PIN 		4
#define TRIGGER_PINx 	PIND
#define TRIGGER_PORTx	PORTD

#define TRANSMIT_PIN		6
#define TRANSMIT_DDRx	DDRD

#define RECEIVER_PIN 	PB0
#define RECEIVER_PORTx 	PORTB

#define NOZZLE_R_PIN		1
#define NOZZLE_G_PIN		2
#define NOZZLE_B_PIN		3
#define NOZZLE_PORTx		PORTC
#define NOZZLE_DDRx		DDRC

#define VEST_PORTx		PORTB
#define VEST_DDRx		DDRB
#define VEST_R_PIN		PB3

#define VIBRATOR_PIN 	5
#define VIBRATOR_DDRx	DDRD
#define VIBRATOR_PORTx	PORTD

#define BUZZER_PIN 		3
#define BUZZER_DDRx		DDRD
#define BUZZER_PORTx 	PORTD

#endif

#endif /* LOCALCODE_BOARD_PINS_H_ */

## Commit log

2016-05-05 Added a folder for the electronics scematic of the main board!
    [MainBoard.kicad_pcb, MainBoard.sch, _saved_file572BD501.sch]
2016-05-06 More work on the electronics scematics, slowly starting to get the hang of it.
    [MainBoard.kicad_pcb, MainBoard.sch]
2016-05-07 Hopefully developed the final version of the prototype electronics.
    [MainBoard.sch]
2016-05-09 First implementation of the eclipse code, as well as some slight further changes to the electronics board.
    [MainBoard.kicad_pcb, MainBoard.sch]
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2016-05-12 Added a first 3D Model, a simplistic IR shield.
    [IR_LED_Shielding.scad]
2016-05-12 Moved the Lasertag.FCStd file to a proper position.
    [Gun.FCStd]
2016-05-12 Moved the code of the Nozzle RGB to a nested namespace for some extra clean code.
2016-05-12 Added an implementation for the IR-System IR_LED class that uses the TIMER0 for PWM.
2016-05-21 Debugging & moving the Board::init() code down to be able to use all function.
2016-05-23 Added a 'Pins.h' to define all necessary pins, making other boards easier to use later on!
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2016-05-23 General mods, added a 'infinite time' mode for the game timer, and attempted optimisation!
2016-05-27 Added timer-countdown for the shield and life regen timers, and implemented some questioning functions.
2016-05-28 Added some KiCad project files for a test target to train shooting on!
    [TestTarget.kicad_pcb, TestTarget.sch]
2016-05-30 Added a first layout for a TestTarget casing!
    [TestTarget.scad]
2016-06-03 Some more tweaks & finishing of the 3D model.
    [TestTarget.scad]
2016-06-21 Changed the IR Shielding to be more elongated (less light spread)
    [IR_LED_Shielding.scad]
2016-06-21 Added a first prototype holder for the lasertag gun system. May even become future main design!
    [M_Gun_Holder.fcstd]
2016-06-21 Added a first basic implementation of a haptic feedback system! (Vibration)
    [Pins.h]
2016-06-21 Added the buzzer & sound effects! (& tweaks)
    [Pins.h, main.cpp]
2017-07-14 Adjusted electronics for new knowledge :3
    [MainBoard.kicad_pcb, MainBoard.sch]
2017-07-14 ... What was I doing :S
    [TestTarget.kicad_pcb, TestTarget.sch]
2017-07-19 Initial modifications. Moved RGB-Muzzle for RX/TX lines, fixed front muzzle LEDs
    [MainBoard.sch]
2017-07-21 Small cleanup of schematic & footprint
    [MainBoard.kicad_pcb, MainBoard.sch]
2017-07-21 Associated Footprints
    [MainBoard.sch]
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2017-07-21 Ensured correct Pin-Configuration
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2017-07-25 Freshy new IR Focus piece!
    [EDGE_IRFocus.fcstd]
2017-07-27 Removed old LED's implementation, fixed Flag-Set error
    See PR #7 for more infos.
    [main.cpp]
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2017-07-29 Made the IR Shield longer and wider -> More range!
    [EDGE_IRFocus.fcstd]
2017-07-30 Threw in some simple covers for the shoulder pads!
    [BottomCovering.fcstd, RGBCovering.fcstd, SecurityPinClip.fcstd]
2017-07-30 Added a proper covering for the haptic feedback device (the vibrator >.<)
    [VibratorCover.fcstd]
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2017-08-11 Added a invert button option :3
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2017-08-16 Fixed a couple of sub thread names
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2017-08-19 Changed ID Handout for retained MSG fix
    [Lasertag.lua]
2017-09-29 Fixed disconnect bug, 1sec g timer, on_register player prep
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2017-11-14 PR #11, fixed shot ID not being sent with the packet.
    [main.cpp]
2017-11-14 *groan* Typo fixing. Oh well
    [init.lua]
2017-11-22 Removed old debug & fixed string compare
    [Lasertag.lua]
2017-11-27 Added SAFEMMODE (on Crash, only reload ConsoleRedir)
    [init.lua]
2017-11-28 Fixed missing `target` option It was replaced by simply providing a Lasertag player
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2017-11-29 Added built-in display of error situation Setting the team to red, flashing brightly, that should work.
    [init.lua]
2017-11-29 Fixed SAFEMODE behavior, reduced safemode clear timer
    [init.lua]
2017-11-30 Begun phasing out old NoAmmoShoot file For issue #13 and #14 both
    [Lasertag.lua, init.lua]
2017-11-30 Added first framework of handling of fire All in line with #13, later #14
    The new system gives good default values, and complete server-control
2017-12-04 Fixes and changes. Loafs
    - Variable name fixes (playerDead vs. player.dead)
    - Player death control MQTT Topic + status messages
    - UART Command for button press added
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2017-12-16 Added 16-bit instead of 8-bit vibrate time
    [Lasertag.lua, main.cpp]
2017-12-17 Changed buzzer-related values to 16bit
    [Lasertag.lua, main.cpp]
2017-12-17 Fixed ESP-Init file, added repeatable restarting
    [init.lua]
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2017-12-18 Added board-code reset hook to ESP reconnect
    [main.cpp]
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2017-12-22 Trying to fix the ammo capture ...
    [Lasertag.lua]
2018-01-04 Added ESPComs Endpoint for vibrations
    [main.cpp]
2018-01-04 Added vibrate pattern command
    [Lasertag.lua]
2018-01-29 Added game-ticks (fixed-frequency 5Hz)
2018-01-31 Added gerber file directory
    [MainBoard-B.Cu.gbr, MainBoard-B.Mask.gbr, MainBoard-B.SilkS.gbr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]
2018-01-31 First implement of SMD components
    [MainBoard-B.Cu.gbr, MainBoard-B.Mask.gbr, MainBoard-B.SilkS.gbr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]
2018-02-02 Preparing for major PCB changes!
    [MainBoard.kicad_pcb, MainBoard.sch]
2018-02-06 More SMD additions
    [MainBoard.kicad_pcb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]
2018-02-07 Final small changes
    [MainBoard.kicad_pcb, MainBoard.sch]
2018-04-04 Finalized schematics and Gerbers - for now
    [MainBoard-B.Cu.gbr, MainBoard-B.Mask.gbr, MainBoard-B.SilkS.gbr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]
2018-05-07 Added fix to make ESP start better
    [main.cpp]
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2019-01-02 Began working on hardware R3
    [MainBoard.kicad_pcb, MainBoard.sch, Peripherals.sch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]
2019-01-05 Rev 3.0 is now done!
    [MainBoard.sch, Peripherals.sch, Power.sch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]
2019-01-06 Last few tweaks, i.e. fixing ground plane
    [MainBoard.kicad_pcb, MainBoard.sch]
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2019-01-09 Finally fixed LEDC + Light Sleep!
    [main.cpp]
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2019-01-24 Adjusted a few resistor values, added I2S pinout
    [MainBoard.sch, USB_Connection.sch]
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2019-02-02 Tweaked animation thread to properly clear in DISCHARGED, added better battery readings
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2019-02-25 Added larger app partition (more audio space)
    [partitions.csv]
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2019-03-16 Added vibration feedback to the flashing
    [animatorThread.cpp]
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2019-04-28 Reverted to Lasertag Raspberry and tuned some speeds :>
    [main.cpp]
2019-05-08 Small tweaks and fixes here and there
    [animatorThread.cpp, main.cpp]
2019-05-10 Small fixes for #47
    [setup.cpp]
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2019-07-10 Began reworking a few PCB elements
    [MainBoard.kicad_pcb, Peripherals.sch]
2019-07-11 Began rework to even better hardware
    [MainBoard.kicad_pcb, MainBoard.sch, Peripherals.sch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]
2019-07-11 Fixed footprint assignment
    [MainBoard.kicad_pcb, Peripherals.sch]
2019-07-17 Temporary polishing of PCB
    [MainBoard.kicad_pcb, MainBoard.sch, Peripherals.sch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]
2019-08-29 Began reworking the PCB
    [MainBoard.sch, Power.sch]
2019-08-29 Added nav switch models
    [NAV_SWITCH.STEP]
2019-08-29 Began reworking sections
    [MainBoard.kicad_pcb, MainBoard.sch, Peripherals.sch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]
2019-08-30 Continued work on the current electronics
    [MainBoard.kicad_pcb, MainBoard.sch, Peripherals.sch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]
2019-09-05 Last changes for a functional Lasertag, ordered!
    [MainBoard.csv, MainBoard.kicad_pcb, MainBoard.sch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]
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2019-09-19 Reduced WiFi power to prevent brownouts
2019-09-19 Resolve remaining review errors
    [animatorThread.cpp]
2019-09-19 move WiFi initialization to player
    The new init will only run in the "normal" mode, not in Charging or
    Discharged modes
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2019-09-20 Add nav switch read function
    Special care has to be taken for read order, due to
    false but workable wiring.
    Capacitive charging due to low pullups require the PIN_CTRL_DOWN pin to
    be pulled high as much as possible
2019-09-20 fix the MQTT pub path
    [setup.cpp]
2019-09-20 Fix wrong use of player.deviceID
    Due to it now not being const, a getter function will instead be used
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2019-09-28 Add new vibration command
    [animatorThread.cpp]
2019-09-29 Improve vibration handling
    This new way completely prioritizes certain vibration types. Before,
    various modes of vibration could've still mixed together awkwardly.
    [animatorThread.cpp]
2019-10-16 Begin work on the single-sided sensor board
    [SensorBoard.kicad_pcb, SensorBoard.sch]
2019-10-16 Adjust game thread to only handle phases
    The new system is much simpler, not differentiating much between types
    of phases, and instead just allowing the game to handle much
2019-10-16 Improve existing standard hooks
    This will mainly implement a few new options, but majorly removes the
    old RandomTeam system and replaces it with a new TeamSelector that uses
    the gyro and nav switch!
    Plus, the new regenerators and damagers can be filtered per-team,
    allowing asymmetric team options!
2019-10-16 Improve game phase switching
    By providing better allowed phase fetching as well as a proper @lastTick
    timer reset
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2020-08-22 Change a few names to use DigiKey Part Number
    [MainBoard.csv, Power.sch, USB_Connection.sch]
2021-06-08 Tweak... Everything, oh wow
    [partitions.csv]
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2021-06-21 Add DRV vibration motor and adjust a few extra topics
    [animatorThread.cpp, setup.cpp]
2021-06-22 Modify board for the v3.3 release-ish
    [Autogenerated_BOM.csv, BOM.csv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]
